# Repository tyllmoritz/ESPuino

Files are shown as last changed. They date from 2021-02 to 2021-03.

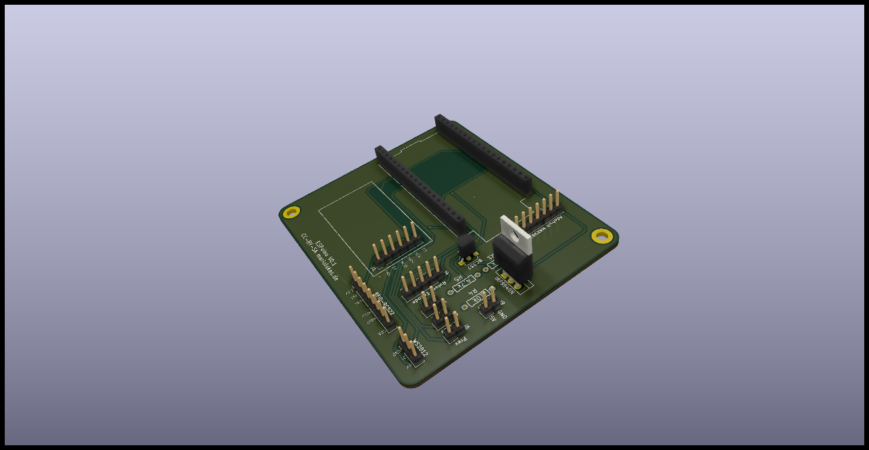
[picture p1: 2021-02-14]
PCBs/ESP32_Breakout_Carrier/Pictures/3d-model_without-ESP32.png

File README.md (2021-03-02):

# ESPuino - rfid-based musiccontroller based on ESP32 with I2S-DAC-support

## NEWS
* As the creator of TonUINO claims it's trademark right, my project has been renamed to ESPuino. I'm totally respecting this and have to admit that I've been not aware of that. However, I instantly renamed everything and hopefully I didn't forget any parts. Since my repository has moved, please make sure (at least if you're using git) to change the URL of your local repository. An explanation was kindly [written by user](https://github.com/biologist79/ESPuino/issues/81).
* Please note: inline with the renaming of the project, MQTT-topics were changed as well as they've been including the old name. Please make sure to change your local MQTT-configuration as well. Sorry to [those](https://github.com/biologist79/ESPuino/issues/83) that spent time on this to point out.
* EN: I've set up a primarily German-speaking community with much documentation. Also an international corner for non-German-speakers is available at https://forum.espuino.de. Github-Login can be used there but it's not necessary.
* DE: Ich habe ein primär deutschsprachiges Forum aufgesetzt, welches ich mit reichlich Doku versehen habe. Würde mich freuen, euch dort zu sehen: https://forum.espuino.de. Ihr könnt euch dort mit eurem Github-Login einloggen, jedoch auch "normal" anmelden. Dokumenation findet ihr insbesondere hier: https://forum.espuino.de/c/dokumentation/anleitungen/10
## Changelog
Moved to [another location](changelog.md) as it became to prominent here. Only last three events are kept:
* 25.02.2020: Added support for dynamic button-layout. Rotary-encoder is now optional and up to five buttons can be used.
* 25.02.2020: Actions can be freely assigned to buttons (multi-button(s), single-button(s) (short), single-button(s) (long))
* 25.02.2020: Added support for webcontrol: basic control (volume, play/pause, next, previous, first, last track) can now be controlled via webgui.
* 25.02.2020: Added support for .m4a and .wav-files.
* 26.02.2020: Shutdown via webgui is now available.
Thanks @QDaniel for the idea + basic implementation (first three features named above)!
## Known bugs
* Some webstreams don't run. Guess it's a combination of saturated connection-pool and lack of heap-memory. Works probably better if ESP32-WROVER (e.g. Lolin D32 pro) is used, as this chip has PSRAM. Advice: Don't enable modules (e.g. MQTT) if you don't need them as this could save memory (and trouble).
* English translation for webgui is currently pretty outdated. This will be fixed soon when i18n-support will be integrated.
## ESPuino - what's that?
The basic idea of ESPuino is to provide a way, to use the Arduino-platform for a music-control-concept that supports locally stored music-files without DRM-restrictions. This basically means that RFID-tags are used to direct a music-player. Even for kids this concept is simple: place an RFID-object (card, character) on top of a box and the music starts to play. Place another RFID-object on it and anything else is played. Simple as that.

The core of my implementation is based on the popular [ESP32 by Espressif](https://www.espressif.com/en/products/hardware/esp32/overview). Having WiFi-support out-of-the-box makes it possible to provide further features like an integrated FTP-server (to feed the player with music), smarthome-integration via MQTT, webradio and administration via webgui. However, my primary focus was to port the project to a modular base. Said this mp3-decoding is done in software with a dedicated uSD-card-slot and music-output is done via I2S-protocol. I did all my tests on [Adafruit's MAX98357A](https://learn.adafruit.com/adafruit-max98357-i2s-class-d-mono-amp/pinouts), [UDA1334](https://www.adafruit.com/product/3678) and [headphone-pcb](https://github.com/biologist79/ESPuino/tree/master/PCBs/Headphone%20with%20PCM5102a%20and%20TDA1308). Hopefully, not only in theory, other DACs that support I2S can be used as well.

## Hardware-setup
The heart of my project is an ESP32 on a [Wemos Lolin32 development-board](https://www.ebay.de/itm/4MB-Flash-WEMOS-Lolin32-V1-0-0-WIFI-Bluetooth-Card-Based-ESP-32-ESP-WROOM-32/162716855489). If ordered in China (Aliexpress, eBay e.g.) it's pretty cheap (around 4€) but even in Europe it's only around 8€. Make sure to install the drivers for the USB/Serial-chip (CP2102 e.g.). But probably it's better to use it's successor (which has battery-measurement already included): [Wemos Lolin D32](https://de.aliexpress.com/item/32808551116.html). Or, if you're planning to hear webstreams regularly, [Wemos Lolin D32 pro](https://de.aliexpress.com/item/32883116057.html) might be a good decision. It comes with uSD-slot onboard and because of its ESP32-WROVER-B has PSRAM included. PSRAM is used as webstream-cache and might be used more intensively in future.
* [MAX98357A (like Adafruit's)](https://de.aliexpress.com/item/32999952454.html)
* [uSD-card-reader; 3.3V only; supports SPI + SD-MMC](https://www.ebay.de/itm/Micro-SPI-Kartenleser-Card-Reader-2GB-SD-8GB-SDHC-Card-3-3V-ESP8266-Arduino-NEU/333796577968) or [cheaper](https://de.aliexpress.com/item/4000899753727.html)
* [RFID-reader RC-522](https://www.amazon.de/AZDelivery-Reader-Arduino-Raspberry-gratis/dp/B074S8MRQ7)
* [RFID-reader PN5180](https://de.aliexpress.com/item/4001278551831.html)
* [RFID-tags](https://www.amazon.de/AZDelivery-Keycard-56MHz-Schlüsselkarte-Karte/dp/B07TVJPTM7)
* [Neopixel-ring](https://de.aliexpress.com/item/32673883645.html)
* [Rotary Encoder](https://de.aliexpress.com/item/33041814942.html)
* [Buttons](https://de.aliexpress.com/item/32896285438.html)
* [Speaker](https://www.visaton.de/de/produkte/chassiszubehoer/breitband-systeme/fr-7-4-ohm)
* uSD-card: doesn't have to be a super-fast one; µC is limiting the throughput. Tested 32GB without any problems.
* uSD in SD-MMC (1 Bit) mode: Several devkits with onboard SD slot have support for this mode, e.g.: (https://de.aliexpress.com/item/4001229463219.html)
* optional replace the RFID-reader with a the better one: PN5180 comes with better RFID-range, less power-consumption and support for ISO-15693 / iCode SLIX2 tags (https://www.bing.com/shop?q=pn5180&FORM=SHOPTB)

## Getting Started
* Arduino-IDE can be used but you need to satisfy dependencies for all the libraries listed in `platformio.ini` manually.
* Instead I recommend to install Microsoft's [Visual Studio Code](https://code.visualstudio.com/). This is a popular and powerful IDE that gives you the ability to install tons of (well-supported) plugins.
* Install [Platformio Plugin](https://platformio.org/install/ide?install=vscode) into [Visual Studio Code](https://code.visualstudio.com/) and make sure to have a look at the [documentation](https://docs.platformio.org/en/latest/integration/ide/pioide.html). Step-by-step-manual is available [here](https://randomnerdtutorials.com/vs-code-platformio-ide-esp32-esp8266-arduino/.)
* Install [Git](https://git-scm.com/downloads) and make a copy ("clone") my repository to your local computer using `git clone https://github.com/biologist79/ESPuino.git`. Using git you can keep your local repository easily up to date without doing copy'n'paste. To keep it up to date run `git pull origin master`. Further infos [here}(https://stackoverflow.com/questions/1443210/updating-a-local-repository-with-changes-from-a-github-repository).
* (Optional) Install [Gitlens](https://marketplace.visualstudio.com/items?itemName=eamodio.gitlens) as plugin (to have advanced Git-support).
* Now, that the git-repository is saved locally, import this folder into Platformio as a project.
* There's a file called `platformio.ini`, that contains the configuration for different develboards (e.g. env:lolin32). Platformio supports hundrets of boards out of the box. So probably you need to change/extend that configuration. Guess Lolin32 is described in platformio.ini but you need Lolin D32, then lookup Platformio's [documentation](https://docs.platformio.org/en/latest/boards/espressif32/lolin_d32.html) to know what to change.
* `upload_port` and `monitor_port` should be autodetected (by the USB-ID of the serial-adapter). If this fails, please set these values depending on your operating system (Windows, Mac OS, Linux).
* Edit `src/settings.h` according your needs. Especially don't forget to set `HAL` depending on your develboard.
* Edit board-specific (`HAL`) config-file (e.g. `settings-lolin32.h` for Lolin32 or `settings-lolin_d32.h` for Lolin D32). If you're running a board that is not listed there: start with `settings-custom.h` and change it according your needs.
* Connect your develboard via USB, click the alien-head to the left and run `Upload and Monitor`. All libraries necessary should be fetched in background now followed by code-compilation. After that, your ESP32 is flashed with the firmware. Depending on your develboard it might me necessary to push a button in order to allow ESP32 to enter flashmode (not necessary für Lolin32, D32 und D32 pro).
* Now have a look at the serial-output at the bottom of Visual Studio Code's windows. At the first run there might appear a few error-messages (related to missing entries in NVS). Don't worry, this is just normal. However, make sure SD is running as this is mandatory!
* If everything ran fine, at the first run, ESPuino should open an access-point with the name "ESPuino". Join this WiFi with your computer (or mobile) and enter `192.168.4.1` to your webbrowser. Enter WiFi-credentials and the hostname. After saving the configuraton, restart ESPuino. Hint: I tried to connect this access-point via Android mobile. Basically that's no problem, but as my mobile detected there'd be no internet-connection, it keept LTE-connection open and prevented me from connecting to `192.168.4.1`. So if in doubts use a computer.
* After reboot ESPuino tries to join your WiFi (with the credentials previously entered). If that was successful, an IP is shown in the serial-console of Visual Studio Code. You can call ESPuino's GUI using a webbrowser via this IP; make sure to allow Javascript. If mDNS-feature is active in `src/settings.h`, you can use the hostname configured extended by .local instead the IP. So if you configured `espuino` as hostname, you can use `espuino.local` for webgui and FTP.
* Via FTP you can upload data (but don't expect it to be super fast). It's round about 185 kb/s if SD is in SPI-mode and 310 kB/s if SD is in MMC-mode.
* FTP needs to be activated after boot! Don't forget to assign action `ENABLE_FTP_SERVER` in `settings.h` to be able to activate it. Neopixel flashes green (1x) if enabling was successful. It'll be disabled automatically after next reboot. Means: you have to enable it every time you need it (if reboot was in between). Sounds annoying and maybe it is, but's running this way in order to have more heap-memory available (for webstream) if FTP isn't running.
* Via webbrowser you can configure various settings and pair RFID-tags with actions. If MQTT/FTP-support was not compiled, their config-tabs won't appear.

## Prerequisites / tipps
* Open settings.h
* choose if optional modules (e.g. MQTT, FTP, Neopixel) should be compiled/enabled
* Make sure to edit/review button-layout. Default-design is three buttons and a rotary-encoder. All actions available are listed in `values.h` (values >= 100).
* For debugging-purposes serialDebug can be set to ERROR, NOTICE, INFO or DEBUG.
* If MQTT=yes, set the IP or hostname of the MQTT-server accordingly and check the MQTT-topics (states and commands)
* Advice: don't enable MQTT if there's no broker around because network-timeouts can really be a PITA.
* If Neopixel enabled: set NUM_LEDS to the LED-number of your Neopixel-ring and define the Neopixel-type using `#define CHIPSET`
* If you're using Arduino-IDE please make sure to change ESP32's partition-layout to `No OTA (2MB APP/2MB Spiffs)` as otherwise the sketch won't fit into the flash-memory.
* Open board-specific config-file and edit according your needs.
* If you want to monitor battery's voltage, make sure to enable `MEASURE_BATTERY_VOLTAGE`. Use a voltage-divider as voltage of a LiPo is way too high for ESP32 (only 3.3V supported!). For my tests I connected VBat with a serial connection of 130k + 130k resistors (VBat(+)--130k--X--130k--VBat(-)). X is the measure-point where to connect the GPIO to. If using Lolin D32 or Lolin D32 pro, make sure to leave both resistor-values unchanged at 100k. Same for GPIO: unchanged at 35.
Please note: via GUI upper and lower voltage cut-offs for visualisation of battery-voltage (Neopixel) is available. Additional GUI-configurable values are interval (in minutes) for checking battery voltage and the cut off-voltage below whose a warning is shown via Neopixel.
* If you're using a headphone-pcb with a [headphone jack](https://www.conrad.de/de/p/cliff-fcr1295-klinken-steckverbinder-3-5-mm-buchse-einbau-horizontal-polzahl-3-stereo-schwarz-1-st-705830.html) that has a pin to indicate if there's a plug, you can use this signal along with the feature `HEADPHONE_ADJUST_ENABLE` to limit the maximum headphone-voltage automatically. As per default you have to invert this signal (with a P-channel MOSFET) and connect it to GPIO22.
* Enabling `SHUTDOWN_IF_SD_BOOT_FAILS` is really recommended if you run your ESPuino in battery-mode without having a restart-button exposed to the outside of ESPuino's enclosure. Because otherwise there's no way to restart your ESPuino and the error-state will remain until battery is empty (or you open the enclosure, hehe).
* Enabling `PLAY_LAST_RFID_AFTER_REBOOT` will tell ESPuino to remember the last RFID-tag played after next reboot. So rebooting ESPuino will end up in autoplay. I don't really recommend this feature because if you use it along with a webstream, in case of streaming-issues this might end up in an infinite loop.

## SD-card: SPI or SD-MMC (1 bit)-mode?
Having SD working is mandatory. However, there are two modes available to access SD-cards: SPI and SD-MMC (1 bit).<br />
Advantages SD-MMC (1 bit) over SPI:
* Needs only three GPIOs (instead of four)
* It's faster. FTP-upload: 298 kiB vs 178 kiB. HTTP-upload: 372 kiB vs 184 kiB. (tested with filesize of 70.7 MiB.<br />
So why using SPI if SD-MMC seems to be better? The primary problem of SD-MMC is: you cannot choose different GPIOs. That doesn't sound bad but this can (depending on the uSD-card-reader-module) be a problem because maybe GPIO2 is pulled HIGH to 3.3V by a 10k-resistor. For example this is the case when using the reader-module named above in hardware-setup. It's a problem because if GPIO2 is pulled high at boot, ESP32 doesn't enter flash-mode. As soon as flash-mode is entered, it's no longer a problem. However, this behaviour can be an issue if ESP32 is deeply "burried" in ESPuino's enclosure and you want to update its firmware. But fortunately there's a way to bypass this problem: remove the [pullup-resistor shown in the picture](https://raw.githubusercontent.com/biologist79/ESPuino/master/pictures/Pullup-removal.jpg). It can be removed safely because if MMC-mode is set, pullup is done in software using `pinMode(2, INPUT_PULLUP);`. So it's not really a problem but you have to take note of that!

## RFID: RC522 or PN5180?
RC522 is so to say the Tonuino-standard. It's cheap and works, but RFID-tag has to be placed near the reader. PN5180 instead has better RFID range/sensitivity and can read ISO-15693 / iCode SLIX2-tags aka 'Tonies' (you need a password to read Tonies). You can also wake-up the board with the card. Disadvantages: is a bit more expensive and needs more GPIOs (6/7 instead of 4). Refer PN5180's wire-section below for further informations. Hint: if using 3.3V make sure to connect PN5180 to +5V AND 3.3V. Sounds weird but it's necessary.

## 3.3 or 5V?
* Why 3.3V? Because: if you plan to use battery-mode with a LiPo, there's no 5 V available (unless USB is connected).
That's why my design's focus is 3.3 V. If you want to use 5 V - do so, but be advised it's not compatible with LiPo-battery-mode. The Mosfet-circuit for saving power in deepsleep (see [Lolin32-schematics](https://github.com/biologist79/ESPuino/blob/master/PCBs/Wemos%20Lolin32/Pictures/Tonuino%20V2-Schematics.pdf) as reference) works as well for 5 V.
* MAX98357a: provides more power at 5 V but also runs at 3.3 V. Anyway: it's still loud enough (in my opinion).
* Neopixel: specification says it needs 5 V but also runs at 3.3 V.
* RC522: needs 3.3 V (don't power with 5 V!)
* PN5180: at 3.3 V make sure to connect both 5 V and 3.3 V-pins to 3.3 V.
* SD: needs 3.3 V but if voltage-regulator is onboard, it can be connected to 5 V as well
* Rotary encoder: 3.3 V (don't power with 5 V! Encoder doens't care if connected to 3.3 or 5 V, but GPIOs of ESP32 do!)

## Wiring (general)
Depending on the develboard you're using and the needs you have, there are different options available.
A lot of wiring is necessary to get ESPuino working. After my first experiments on a breadboard I soldered all the stuff onto a PCB in order to avoid wild-west-cabling. Especially for the interconnect between µC and uSD-card-reader make sure to use short wires (like 10cm or so)! As of my experience with a breadbord, male/male-connectors are better than female/female-connectors. Important: you can easily connect another I2S-DACs by just connecting them in parallel to the I2S-pins (DIN, BCLK, LRC). This is true for example if you plan to integrate a [line/headphone-pcb](https://www.adafruit.com/product/3678). In general, this runs fine. But unfortunately especially this board lacks of a headphone jack, that takes note if a plug is inserted or not. Best way is to use a [headphone jack](https://www.conrad.de/de/p/cliff-fcr1295-klinken-steckverbinder-3-5-mm-buchse-einbau-horizontal-polzahl-3-stereo-schwarz-1-st-705830.html) that has a pin that is pulled to GND, if there's no plug and vice versa. Using for example a MOSFET-circuit, this GND-signal can be inverted in a way, that MAX98357.SD is pulled down to GND if there's a plug. Doing that will mute MAX98537a and so turn off the speaker immediately if there's a plug and vice versa. Have a look at the PCB-folder in order to view the detailed solution. Here's an example for such a [headphone-pcb](https://github.com/biologist79/ESPuino/tree/master/PCBs/Headphone%20with%20PCM5102a%20and%20TDA1308) that makes use of GND.<br />
Have a look at the PCB-folder. I provided PCBs for a number of develboards. Probably this makes things easier for you.

## Wiring (2 SPI-instances: RC522 + SD + 3 buttons + rotary-encoder)
Uses two SPI-instances. The first one for the RFID-reader and the second for SD-card-reader. This is also the [setup, I personally use](https://github.com/biologist79/ESPuino/tree/master/PCBs/Wemos%20Lolin32).<br />
| ESP32 (GPIO)  | Hardware | Pin | Comment |
| --- | --- | --- | --- |
| 3.3 (5) V | SD-reader | VCC | Connect to p-channel MOSFET for power-saving when µC is off  |
| GND | SD-reader | GND | |
| 15 | SD-reader | CS | |
| 13 | SD-reader | MOSI | |
| 16 | SD-reader | MISO | |
| 14 | SD-reader | SCK | |
| 3.3 V | RFID-reader | 3.3V | (Connect directly to GPIO 17 for power-saving when µC is off)  |
| GND | RFID-reader | GND | |
| 21 | RFID-reader | CS/SDA | |
| 23 | RFID-reader | MOSI | |
| 19 | RFID-reader | MISO | |
| 18 | RFID-reader | SCK | |
| 5 / 3.3 V | MAX98357 | VIN | Connect to p-channel MOSFET for power-saving when µC is off  |
| GND | MAX98357 | GND | |
| 25 | MAX98357 | DIN | |
| 27 | MAX98357 | BCLK | |
| 26 | MAX98357 | LRC | |
| --- | MAX98357 | SD | Info: if pulled down to GND amp will turn off |
| 34 | Rotary encoder | CLK | Change CLK with DT if you want to change the direction of RE |
| 35 | Rotary encoder | DT | Change CLK with DT if you want to change the direction of RE |
| 32 | Rotary encoder | BUTTON | |
| 3.3 V | Rotary encoder | + | |
| GND | Rotary encoder | GND | |
| 4 | Button (next) | | |
| GND | Button (next) | | |
| 2 | Button (previous) | | |
| GND | Button (previous) | | |
| 5 | Button (pause/play) | | |
| GND | Button (pause/play) | | |
| 3.3 V | Neopixel | V | Connect to p-channel MOSFET for power-saving when µC is off  |
| GND | Neopixel | G | |
| 12 | Neopixel | DI | |
| 17 | N-channel Mosfet | Gate | |
| 33 | Voltage-divider / BAT | | Optional: voltage-divider to monitor battery-voltage |
| 22 | Headphone jack | | Optional: if pulled to ground, headphone-volume is set |

Optionally, GPIO 17 can be used to drive a Mosfet-circuit in order to switch off peripherals (SD, Neopixel, RFID and MAX98357a) if ESP32 is in deepsleep. Please refer the schematics for my [Lolin32-PCB](https://github.com/biologist79/ESPuino/blob/master/PCBs/Wemos%20Lolin32/Pictures/Tonuino-Lolin32-Schematics.pdf) for further informations. If you need further informations on transistor-circuits visit this [website](https://dl6gl.de/schalten-mit-transistoren.html). <br />
In general I recommend using a [uSD-card-reader](https://www.ebay.de/itm/Micro-SPI-Kartenleser-Card-Reader-2GB-SD-8GB-SDHC-Card-3-3V-ESP8266-Arduino-NEU/333796577968) that can be run solely with 3.3V (doesn't have a voltage-regulator). This is because if 3.3V go through the voltage regulator a small voltage-drop will be introduced, which may lead to SD-malfunction as the resulting voltage is a bit too low. Vice versa if you want to connect your reader solely to 5V, make sure to have one WITH a voltage regulator :-). And by the way: when LiPo-battery is connected, there's no 5V. That's why I designed my [Lolin-PCBs](https://github.com/biologist79/ESPuino/tree/master/PCBs/Wemos%20Lolin32) with 3.3V only.

## Wiring (SD-card in 1 Bit SD-MMC mode) different to above
| ESP32 (GPIO)  | Hardware | Pin | Comment |
| --- | --- | --- | --- |
| -- | SD-reader | CS | no CS required |
| 15 | SD-reader | MOSI | |
| 2 | SD-reader | MISO | make sure there's no [hardware-pullup](https://raw.githubusercontent.com/biologist79/ESPuino/master/pictures/Pullup-removal.jpg) for MISO |
| 14 | SD-reader | SCK | |

Make sure to enable `SD_MMC_1BIT_MODE` if you want to use this feature. Don't(!) enable `SINGLE_SPI_ENABLE`. SD-MMC-mode requires these fixed PINs listed above. You can find a good comparison of different SD-card-modes here: (https://www.instructables.com/Select-SD-Interface-for-ESP32/).
Advice: Double check that above PINs are not used elsewhere (e.g. GPIO2 is used as PREVIOUS_BUTTON as per default in settings.h).

## Wiring (1 SPI-instance: RC522 + SD + 3 buttons + rotary-encoder) [EXPERIMENTAL, maybe not working!]
Basically the same as using 2 SPI-instances but...
In this case RFID-reader + SD-reader share SPI's SCK, MISO and MOSI. But make sure to use different CS-pins. Have to admit I had some problems to get this running. Seems to be connected properly, but nothing happens when an RFID-tag is applied. Maybe anybody else wants to point out :-)

| ESP32 (GPIO)  | Hardware | Pin | Comment |
| --- | --- | --- | --- |
| 3.3 (5) V | SD-reader | VCC | Connect to p-channel MOSFET for power-saving when µC is off  |
| GND | SD-reader | GND | |
| 15 | SD-reader | CS | Don't share with RFID! |
| 3.3 V | RFID-reader | 3.3V | Connect directly to GPIO 17 for power-saving when µC is off  |
| GND | RFID-reader | GND | |
| 21 | RFID-reader | CS/SDA | Don't share with SD! |
| 23 | RFID+SD-reader | MOSI | |
| 19 | RFID+SD-reader | MISO | |
| 18 | RFID+SD-reader | SCK | |
| 5 / 3.3 V | MAX98357 | VIN | Connect to p-channel MOSFET for power-saving when µC is off  |
| GND | MAX98357 | GND | |
| 25 | MAX98357 | DIN | |
| 27 | MAX98357 | BCLK | |
| 26 | MAX98357 | LRC | |
| --- | MAX98357 | SD | Info: if pulled down to GND amp will turn off |
| 34 | Rotary encoder | CLK | Change CLK with DT if you want to change the direction of RE |
| 35 | Rotary encoder | DT | Change CLK with DT if you want to change the direction of RE |
| 32 | Rotary encoder | BUTTON | |
| 3.3 V | Rotary encoder | + | |
| GND | Rotary encoder | GND | |
| 4 | Button (next) | | |
| GND | Button (next) | | |
| 2 | Button (previous) | | |
| GND | Button (previous) | | |
| 5 | Button (pause/play) | | |
| GND | Button (pause/play) | | |
| 5 / 3.3 V | Neopixel | V | Connect to p-channel MOSFET for power-saving when µC is off  |
| GND | Neopixel | G | |
| 12 | Neopixel | DI | |
| 17 | N-channel Mosfet | Gate | |
| 33 | Voltage-divider / BAT | | Optional: voltage-divider to monitor battery-voltage |
| 22 | Headphone jack | | Optional: if pulled to ground, headphone-volume is set |

## Wiring (PN5180 instead of MFRC522) different to above
PN5180-reader needs at least two more GPIOs: RESET and BUSY. Double check pin-conflicts! `RFID_READER_TYPE_PN5180` needs to be enabled to use this feature. Make sure to disable `RFID_READER_TYPE_MFRC522` if doing so!
You can enable low power card-detection with `PN5180_ENABLE_LPCD`, but this needs another GPIO for IRQ. With low power card detection (LPCD) you can wake-up the ESP32 from deep-sleep just by applying a card to the reader. You need a PN5180-firmware >= 4.0. Most china-boards comes with older firmware. The latest firmware can be flashed with this [project](https://github.com/abidxraihan/PN5180_Updater_ESP32).

| ESP32 (GPIO)  | Hardware | Pin | Comment |
| --- | --- | --- | --- |
| 3.3 V | PN5180 RFID-reader | 3.3V | Connect directly to GPIO 17 for power-saving when µC is off |
| 3.3 V | | 3.3V | For low power card detection mode (LPCD) connect directly to 3.3V |
| 5 / 3.3 V | PN5180 RFID-reader | 5V | Don't forget to connect this pin the same way as 3.3V |
| GND | PN5180 RFID-reader | GND | |
| 21 | PN5180 RFID-reader | CS/SDA | Same as MFRC522. Don't share with SD! |
| 23 | PN5180 RFID-reader | MOSI | Same as MFRC522 |
| 19 | PN5180 RFID-reader | MISO | Same as MFRC522 |
| 18 | PN5180 RFID-reader | SCK | Same as MFRC522 |
| 16 | PN5180 RFID-reader | BUSY | be aware of SD MISO if running in SPI mode |
| 22 | PN5180 RFID-reader | RST | be aware of Headphone jack PIN |
| 39 | PN5180 RFID-reader | IRQ | optional, used for low power card detection (LPCD) |

## Wiring (custom) / different pinout
When using a develboard with SD-card-reader already integrated (Lolin D32 Pro, several TTGO-boards), the pinouts described above my not fit. Feel free to change them according your needs. Additionaly some boards may use one or some of the GPIOs I used for their internal purposes and that reason for are maybe not exposed via pin-headers. However, having them exposed doesn't mean they can be used without limits. This is because some GPIOs have to be logical LOW or HIGH at start/boot for example and this is probably not the case when connecting stuff to it. Feel free to adjust the GPIOs proposed by me (but be adviced it could take a while to get it running). If you encounter problems please refer the board's manual first. <br />
[Here](https://github.com/biologist79/ESPuino/tree/master/Hardware-Plaforms/ESP32-A1S-Audiokit) I described a solution for a board with many GPIOs used internally and a very limited number of GPIOs exposed. That's why I had to use different SPI-GPIOs for RFID as well. Please note I used a slightly modified [RFID-lib](https://github.com/biologist79/ESPuino/tree/master/Hardware-Plaforms/ESP32-A1S-Audiokit/lib/MFRC522) there. Please note: the code-basis is outdated. Will need to re-integrate it into my master-branch...

## WiFi
WiFi is mandatory for webgui, FTP and MQTT. However, WiFi can be temporarily or permanently disabled. There are two ways to do that:
* Use a special modification-card that can be configured via webgui
* Press previous-key (and keep it pressed) + press next-button in parallel shortly. Now release both.
This toggles the current WiFi-status: if it's currently enabled, it will be disabled instantly and vice versa. Please note: this WiFi-status will remain until you change it again, which means, that ESPuino will remember this state after the next reboot. Having Wifi enabled is indicated in idle-mode (no playlist active) with four *white* slow rotating LEDs whereas disabled WiFi is represented by those ones coloured *green*. Bluetooth-mode is indicated by *blue* LEDs.

## Bluetooth
ESPuino can be used as bluetooth-sink (a2dp). This mode can be enabled/disabled via a RFID-modification-card. Applying one will restart ESPuino immediately. Two modes are available which are toggled in between: "normal" and "bluetooth". Normal means: SD + WiFi are available whereas in mode "bluetooth" only bluetooth-support can be provided. If bluetooth is active, this is indicated by four slow rotating *blue* LEDs. Now you can stream to your ESPuino e.g. with your mobile device. Tested this with Android 8 and worked 100% flawless.
## After ESPuino is connected to your WiFi
After bringing ESPuino part of your LAN/WiFi, the 'regular' webgui is available at the IP assigned by your router (or the configured hostname). Using this GUI, you can configure:
* WiFi
* Binding between RFID-tag, file/directory/URL and playMode
* Binding between RFID-tag and a modification-type
* MQTT
* FTP
* Initial volume, maximum volume (speaker / headphone), brightness of Neopixel (nightmode / default) and inactivity-time

Webgui #1:


Webgui #2:


Webgui #3:


Webgui #4:


Webgui #5:


Webgui #6:


Webgui #7:


Webgui: websocket broken:


Webgui: action ok:


Please note: as you apply a RFID-tag to the RFID-reader, the corresponding ID is pushed to the GUI. So there's no need to enter such IDs manually (unless you want to). Filepath can be filled out by selecting a file/directory in the tree.
IMPORTANT: Every time you add, delete or rename stuff on the SD-card, it's necessary to rebuild the json-indexfile. Simply click on the refresh-button below the filetree and wait until it's done. This is because all operations of the filebrowser rely on this file in order to provide a fast way to access all the files and directories.

## Interacting with ESPuino
### Playmodes
It's not just simply playing music; different playmodes are supported:
* `single track` => plays one track one time
* `single track (loop)` => plays one track forever
* `audiobook `=> single file or playlist/folder; last play-position (file and playlist) is saved (when pushing pause or moving to another track) and re-used next time
* `audiobook` (loop) => same as audiobook but loops forever
* `folder/playlist (alph. sorted)` => plays all tracks in alph. order from a folder one time
* `folder/playlist (random order)` => plays all tracks in random order from a folder one time
* `folder/playlist (alph. sorted)` => plays all tracks in alph. order from a folder forever
* `folder/playlist (random order)` => plays all tracks in random order from a folder forever
* `webradio` => always only one "track": plays a webstream

### Modification RFID-tags
There are special RFID-tags, that don't start music by themself but can modify things. If applied a second time, it's previous action/modification will be reversed. Please note: all sleep-modes do dimming (Neopixel) automatically because it's supposed to be used in the evening when going to bed. Well, at least that's my children's indication :-) So first make sure to start the music then use a modification-card in order to apply your desired modification:
* lock/unlock all buttons
* sleep after 5/30/60/120 minutes
* sleep after end of current track
* sleep after end of playlist
* sleep after five tracks
* dimm neopixel
* current track in loop-mode (is "stronger" than playlist-loop but doesn't overwrite it!)
* playlist in loop-mode
* track und playlist loop-mode can both be activated at the same time, but unless track-loop isn't deactivated, playlist-loop won't be effective
* Toggle WiFi (enable/disable) => disabling WiFi while webstream is active will stop the webstream instantly!
* Toggle Bluetooth (enable/disable) => restarts ESPuino immediately

### Neopixel-ring (optional)
Indicates different things. Don't forget configuration of number of LEDs via #define NUM_LEDS
* While booting: every second LED (rotating orange)
* Unable to mount SD: LEDs flashing red (will remain forever unless SD-card is available or `SHUTDOWN_IF_SD_BOOT_FAILS` is active)
* IDLE: four LEDs slow rotating (white if WiFi enabled; green if WiFi disabled)
* BLUETOOTH: four LEDs slow rotating coloured blue
* ERROR: all LEDs flashing red (1x) if an action was not accepted
* OK: all LEDs flashing green (1x) if an action was accepted
* BUSY: violet; four fast rotating LEDs when generating a playlist. Duration depends on the number of files in your playlist.
* track-progress: rainbow; number of LEDs relative to play-progress
* playlist-progress: blue; appears only shortly in playlist-mode with the beginning every new track; number of LEDs relative to progress
* webstream: two slow rotating LEDs that change their colours rainbow-wise as the stream proceeds
* volume: green => red-gradient; number of LEDs relative from current to max volume
* switching off: red-circle that grows until long-press-time is reached
* buttons locked: track-progress-LEDs coloured red
* paused: track-progress-LEDs coloured orange
* rewind: if single-track-loop is activated a LED-rewind is performed when restarting the given track
* (Optional) Undervoltage: flashes three times red if battery-voltage is too low. This voltage-level can be configured via GUI.
* (Optional) Short press of rotary encoder's button provides battery-voltage visualisation via Neopixel. Upper und lower voltage cut-offs can be adjusted via GUI. So for example if lower voltage is set to 3.2 V and upper voltage to 4.2 V, 50% of the LEDs indicate a voltage of 3.7 V.

Please note: some Neopixels use a reversed addressing which leads to the 'problem', that all effects are shown
counter clockwise. If you want to change that behaviour, just enable `NEOPIXEL_REVERSE_ROTATION`.

### Buttons
Important: this section describes my default-design: 3 buttons + rotary-encoder. Feel free to change button-number and button-actions according your needs in `settings.h` and your develboard-specific config-file (e.g. `settings-lolin32.h`). At maximum you can activate five buttons + rotary-encoder.
Minimum duration for long press in ms is defined by `intervalToLongPress`.
* previous (short): previous track / beginning of the first track if pressed while first track is playing
* previous (long): first track of playlist
* next (short): next track of playlist
* next (long): last track of playlist
* pause/play (short/long): pause/play
* rotary encoder (turning): vol +/-
* rotary encoder (button long): switch off (only when on)
* rotary encoder (button short): switch on (when switched off)
* rotary encoder (button short): show battery-voltage via Neopixel (when switched on and `MEASURE_BATTERY_VOLTAGE` is active)
* previous (long; keep pressed) + next (short) + release (both): toggle WiFi enabled/disabled

### Music-play
* Music starts to play right after a valid RFID-tag was applied
* If `PLAY_LAST_RFID_AFTER_REBOOT` is active, ESPuino will remember the last RFID applied => music-autoplay (if in doubts don't use this feature).
* If a folder should be played that contains many mp3s, the playlist generation can take a few seconds. Please note that a file's name including path cannot exceed 255 characters.
* While playlist is generated Neopixel indicates BUSY-mode.
* After last track was played, Neopixel indicates IDLE-mode.
* In audiobook-mode, last play-position is remembered (position in actual file and number of track, respectively) when a new track begins of if pause-button was hit.
* In webstream-mode the stream will instantly stop if WiFi-status is toggled to disabled. ESPuino will return to idle-mode and wait for new RFID-tag.

### Audiobook-mode
This mode is different from the other ones because the last playposition is saved. Playposition is saved when...
* next track starts.
* first/previous/last track requested by button.
* pause was pressed.
* playlist is over (playposition is set back to the first track and file-position 0).
* Please note: last playposition is not saved when applying a new RFID-tag. This is intended because otherwise you woldn't have a possibility to not save it.

### Webinterface-configuration
After having ESPuino running on your ESP32 in your local WiFi, the webinterface-configuration is accessable. Using this GUI you can configure:
* Wifi-configuration (Wifi-SSID, Wifi-password, ESPuino's name (for nameserver))
* Link between RFID-tag and corresponding action
* (optional) MQTT-configuration (broker's IP)
* (optional) FTP-configuration (username and password)
* General-configuration (volume (speaker + headphone), neopixel-brightness (night-mode + initial), sleep after inactivity)
* Basic music-control: first, last, previous, next-track; volume +/-; play/pause

### FTP (optional)
* FTP needs to be activated after boot! Don't forget to assign action `ENABLE_FTP_SERVER` in `settings.h` to be able to activate it! Neopixel flashes green (1x) if enabling was successful. It'll be disabled automatically after next reboot. Means: you have to enable it every time you need it (if reboot was in between). Sounds annoying and maybe it is, but's running this way in order to have more heap-memory available (for webstream) if FTP isn't running.
* In order to avoid exposing uSD-card or disassembling ESPuino all the time for adding new music, it's possible to transfer music to the uSD-card using FTP.
* Default-user and password are set to `esp32` / `esp32` but can be changed later via GUI.
* Make sure to set the max. number of parallel connections to ONE in your FTP-client and the charset to CP437. CP437 is important if you want to use german umlauts (öäüß).
* Secured FTP is not available. So make sure to disable SSL/TLS.
* Software: my recommendation is [Filezilla](https://filezilla-project.org/) as it's free and available for multiple platforms.
* Don't expect a super fast data-transfer; it's around 185 kB/s (SPI-mode) and 310 kB/s (MMC-mode).
* Please note: if music is played in parallel, this rate decrases dramatically! So better stop playback when doing a FTP-transfer.

### Energy saving
As already described in the modify-section, there are different sleepmodes available. Additionaly µC will be put into deepsleep after 10 minutes of inactivity (configurable my maxInactivityTime) unless ESPuino doesn't play music, has a FTP-client connected and any input via buttons. Every button-interaction resets the counter.

### MQTT (optional)
Everything that can be controlled via RFID-tags and buttons, can also be controlled via MQTT (excepting toggling WiFi-status as this doesn't make sense). All manual interactions (buttons, RFID-tags) are also sent to MQTT in parallel, so everything is always in-sync (unless Wifi/MQTT-connection is broken). In my home-setup I'm using [openHAB](https://www.openhab.org/) to "encapsulate" MQTT into a nice GUI, that's accessible via APP + web. I [described](https://github.com/biologist79/ESPuino/tree/master/openHAB) a sample-config for openHAB2. However, meanwhile openHAb3 is available and all the stuff described can also be configured via GUI. Be advised that openHAB is pretty complex and you have to spend some time to get familiar with it.

### Supported file/stream-types
Please refer [ESP32-audioI2S](https://github.com/schreibfaul1/ESP32-audioI2S), as this is the library I used for music-decoding. Make sure to update especially this library regularly as it's development is still in progress.

### Backups
As all assignments between RFID-IDs and actions (playmode, file to play...) is saved in ESP's NVS, the problem is that it's all gone when the ESP is broken. So that's where a backup comes into play. So every time you change or add a new assignment between a RFID-tag and an action via GUI, a backup-file is saved on the uSD-card. The file's name can be changed via `backupFile`. So better don't delete it! Using the webgui you can use the upload-form to import such a file. To be honest: Sometimes I had some issues with Firefox doing this whereas Safari turned out to do it right. Don't know why :-(.

## Smarthome (optional)
As already described, MQTT is supported. In order to use it it's necessary to run a MQTT-broker; [Mosquitto](https://mosquitto.org/) for instance. After connecting to it, ESPuino subscribes to all command-topics. State-topics are used to push states to the broker in order to inform others if anything changed (change of volume, new playlist, new track... name it). Others, like openHAB, subscribe to state-topics end send commands via command-topics. So it's not just limited to openHAB. It's just necessary to use a platform, that supports MQTT. For further informations (and pictures) refer the [subfolder](https://github.com/biologist79/ESPuino/tree/master/openHAB).

## MQTT-topics and their ranges
Feel free to use your own smarthome-environments (instead of openHAB). The MQTT-topics available are described as follows. Please note: if you want to send a command to ESPuino, you have to use a cmnd-topic whereas ESPuino pushes its states back via state-topics. So guess you want to change the volume to 8 you have to send this number via topic-variable `topicLoudnessCmnd`. Immediately after doing to, ESPuino sends a conformation of this command using `topicLoudnessState`. To get hands on MQTT I recommend this [one](https://www.hivemq.com/mqtt-essentials/) as introducton (covers more than you need for ESPuino).

| topic-variable | range | meaning |
| --- | --- | --- |
| topicSleepCmnd | 0 or OFF | Power off ESPuino immediately |
| topicSleepState | ON or OFF | Sends ESPuino's current/last state |
| topicRfidCmnd | 12 digits | Set number of RFID-tag which 'emulates' an RFID-tag (e.g. `123789456089`) |
| topicRfidState | 12 digits | ID of current RFID-tag (if not a modification-card) |
| topicTrackState | String | Sends current track number, total number of tracks and full path of curren track. E.g. "(2/10) /mp3/kinderlieder/Ri ra rutsch.mp3" |
| topicTrackControlCmnd | 1 -> 7 | `1`=stop; `2`=unused!; `3`=play/pause; `4`=next; `5`=prev; `6`=first; `7`=last |
| topicLoudnessCmnd | 0 -> 21 | Set loudness (depends on minVolume / maxVolume) |
| topicLoudnessState | 0 -> 21 | Sends loudness (depends on minVolume / maxVolume |
| topicSleepTimerCmnd | EOP | Power off after end to playlist |
| | EOT | Power off after end of track |
| | EO5T | Power off after end of five tracks |
| | 1 -> 2^32 | Duration in minutes to power off |
| | 0 | Deactivate timer (if active) |
| topicSleepTimerState | various | Sends active timer (`EOP`, `EOT`, `EO5T`, `0`, ...) |
| topicState | Online, Offline | `Online` when powering on, `Offline` when powering off |
| topicCurrentIPv4IP | IPv4-string | Sends ESPuino's IP-address (e.g. `192.168.2.78`) |
| topicLockControlsCmnd | ON, OFF | Set if controls (buttons, rotary encoder) should be locked |
| topicLockControlsState  | ON, OFF | Sends if controls (buttons, rotary encoder) are locked |
| topicPlaymodeState | 0 - 10 | Sends current playmode (single track, audiobook...; see playmodes) |
| topicRepeatModeCmnd | 0 - 3 | Set repeat-mode: `0`=no; `1`=track; `2`=playlist; `3`=both |
| topicRepeatModeState | 0 - 3 | Sends repeat-mode |
| topicLedBrightnessCmnd  | 0 - 255 | Set brightness of Neopixel |
| topicLedBrightnessState | 0 - 255 | Sends brightness of Neopixel |
| topicBatteryVoltage | float | Voltage (e.g. 3.81) |

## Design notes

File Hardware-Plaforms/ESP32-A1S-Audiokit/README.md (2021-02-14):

# ESPuino based on ESP32-A1S Audio-Development-Kit

AI-Tinker released (almost two years ago or so) a development-board that contains an ESP32-A1S, which means a DAC is already included upfront. It's sorta ready to use but in the end, to make it compatible with ESPuino, there's some work waiting.

## Things to know
* As there's a lack of GPIOs, it's necessary to share a single SPI-instance by SD and RFID.
* As per default, [RFID-Lib](https://github.com/miguelbalboa/rfid/) doesn't support to run on non-default-SPI-GPIOs. So that's why I used a [modified one](https://github.com/madias123/STM32duino-RFID-Mp3-Player/tree/master/3d%20party%20libraries%20(modified)/MFRC522).
* The board provides 6 keys but due to lack of free GPIOs, we need them for other purposes. Additionaly the problem is, that all keys are equipped with capacitors (maybe to debounce) which makes it hard to use those GPIOs for other purposes. That's why I unsoldered R66, 67, 68, 69, 70 (all 0 Ohms) to free these GPIOs from the capacitors.
* Please note: key1 still works but if you additionaly want to use keys2-6, you can use GPIO36 along with analogRead() by using voltage-dividers. But first one has to calculate + solder resistor-pairs 56/61, 57/62, 58/63, 59/64 to 'build' those voltage-dividers. Without doing that online Key1 is usable as it doesn't need resistors. However, didn't solder/test dividers so far.
* When switching over to use analogRead() one has to modify buttonHandler() in my code.
* Additionaly I unsoldered resistor R14 in order to deactivate LED D4 (probably not necessary)

## GPIOS
Please note: You need to unsolder R66, 67, 68, 69, 70 first to use the board that way!

| GPIO | Usage | Pin | Comment |
| --- | ---| --- | --- |
| 0 | internal (I2S) | MCLK | |
| 2 | SD (int.) + RFID | SPI.MISO | Solder wire to SD.7 for RFID |
| 4 | Rot. Encoder | BUTTON | Solder wire to SD.8 |
| 5 | Rot. Encoder | CLK | Via 14-pin-header |
| 12 | RFID | SPI.CS | Via JT_MTDI |
| 13 | internal (SD) | SPI.CS | CS for SD |
| 14 | SD (int.) + RFID | SPI.SCK | Via JT_MTMS |
| 15 | SD (int.) + RFID | SPI.MOSI | Via JT_MTDO |
| 18 | Rot. Encoder | DT | Via 14-pin-header |
| 19 | Power | | For switch on/off external hardware via MOSFET (optional) |
| 21 | internal (amp) | | To switch on/off amp |
| 22 | unused? | | Via 14-pin-header |
| 23 | Neopixel | DI | Via 14-pin-header |
| 25 | internal (I2S) | DSIN | |
| 26 | internal (I2S) | LRC | |
| 27 | internal (I2S) | BCLK | |
| 32 | internal (I2C) | CLK | |
| 33 | internal (I2C) | DATA | |
| 34 | internal (SD) | DETECT | To detect if SD is present (not used) |
| 35 | internal (I2S) | DOUT | |
| 36 | internal (Key) | A/D | Analog read for keys 1-6 or digial read for only key 1 |
| 39 | internal (HP) | DETECT | Detects if headphone is plugged in |

Now, question is what to do with GPIO22. Could be used to externally connect keys for analogRead() via voltage-dividers.

## Power-consumption
* IDLE: 105 mA
* Deepsleep (without RFID + Neopixel): 30 mA

## Things to consider
* I didn't battery-power this board (guess it works but didn't test). But as current in deepsleep still is 30 mA, this probably doesn't make sense.
* When using a switch (instead of putting 'only' to deepsleep), GPIO 19 (power) could be omitted. Along with GPIO 22, these buttons could be used as buttons 'previous' and 'next'. Third button could be omitted by assigning short-press-action of rotary-encoder for 'pause/play'.
* In order to safe energy consider the unsolder LEDs.

## Please note
* This one is more or less a project to test whether it's possible to run my fork on this special board. It's not really maintained actively but feel free to contact me in case of questions.
* Some additional informations regarding this board can be found [here](https://www.mikrocontroller.net/topic/474383?goto=6429727) and [here] (https://www.mikrocontroller.net/topic/492149).
* I discovered RFID.RST is uninportant. So you need to initialize it but doesn't matter whether it's connected or not. So I used just anything.

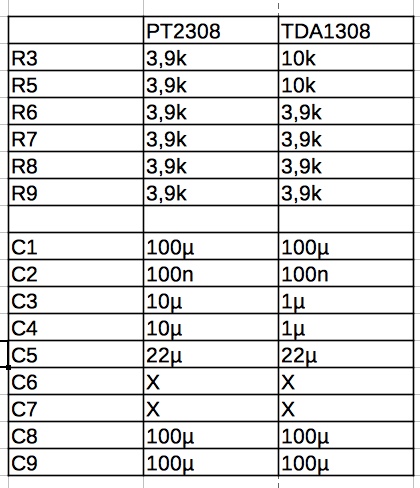
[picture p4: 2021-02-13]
PCBs/Headphone with PCM5102a and TDA1308/KiCad/Element list.jpeg

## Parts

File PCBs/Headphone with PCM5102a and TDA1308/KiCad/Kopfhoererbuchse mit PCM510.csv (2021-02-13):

ID | Bezeichner | Geh+AOQ-use | St | Bezeichnung
1 | IC1 | SOT95P282X145+AC0-5N | 1 | ME6211C33M5G
2 | +ACI-C19 | C18 | C4 | C3+ACI- | C+AF8-0603+AF8-1608Metric+AF8-Pad1.05x0.95mm+AF8-HandSolder | 4 | 1+ALU-
3 | JP1 | SolderJumper+AC0-2+AF8-P1.3mm+AF8-Open+AF8-Pad1.0x1.5mm | 1 | SolderJumper+AF8-2+AF8-Open
4 | Q1 | SOT+AC0-23 | 1 | IRLML6401
5 | J1 | PinHeader+AF8-2x03+AF8-P2.54mm+AF8-Vertical+AF8-large | 1 | Conn+AF8-02x03+AF8-Odd+AF8-Even
6 | U2 | SO+AC0-8+AF8-5.3x6.2mm+AF8-P1.27mm | 1 | TDA1308
7 | U1 | TSSOP+AC0-20+AF8-4.4x6.5mm+AF8-P0.65mm | 1 | PCM5102A
8 | +ACI-R15 | R14 | R13 | R11 | R10+ACI- | R+AF8-0805+AF8-2012Metric+AF8-Pad1.15x1.40mm+AF8-HandSolder | 5 | 470R
9 | +ACI-R12 | R5 | R3 | R2+ACI- | R+AF8-0805+AF8-2012Metric+AF8-Pad1.15x1.40mm+AF8-HandSolder | 4 | 10k
10 | +ACI-C17 | C16 | C14 | C12 | C2+ACI- | C+AF8-0603+AF8-1608Metric+AF8-Pad1.05x0.95mm+AF8-HandSolder | 5 | 100n
11 | +ACI-C15 | C13+ACI- | C+AF8-0603+AF8-1608Metric+AF8-Pad1.05x0.95mm+AF8-HandSolder | 2 | +ACI-2 | 2+ALU-+ACI-
12 | +ACI-C11 | C10+ACI- | C+AF8-0603+AF8-1608Metric+AF8-Pad1.05x0.95mm+AF8-HandSolder | 2 | +ACI-2 | 2n+ACI-
13 | J2 | Jack+AF8-3.5mm+AF8-Cliff+AF8-Horizontal | 1 | AudioJack3+AF8-Dual+AF8-Switch
14 | +ACI-H2 | H1+ACI- | MountingHole+AF8-3.2mm+AF8-M3 | 2 | MountingHole
15 | +ACI-R9 | R8 | R7 | R6+ACI- | R+AF8-0805+AF8-2012Metric+AF8-Pad1.15x1.40mm+AF8-HandSolder | 4 | +ACI-3 | 9k+ACI-
16 | R4 | R+AF8-0805+AF8-2012Metric+AF8-Pad1.15x1.40mm+AF8-HandSolder | 1 | 100k
17 | +ACI-C9 | C8 | C1+ACI- | CP+AF8-Radial+AF8-D6.3mm+AF8-P2.50mm | 3 | 100+ALU-
18 | C5 | CP+AF8-Radial+AF8-D4.0mm+AF8-P1.50mm | 1 | 22+ALU-
1 | L1 | L+AF8-Bourns+AF8-SRN6045TA+AF8-1 | 1 | INDUCTOR
2 | U3 | TSSOP+AC0-8+AF8-4.4x3mm+AF8-P0.65mm | 1 | L6920
3 | +ACI-JP3 | JP2+ACI- | SolderJumper+AC0-3+AF8-P1.3mm+AF8-Bridged2Bar12+AF8-Pad1.0x1.5mm+AF8-NumberLabels | 2 | +ACI-3 | 3 or 5V for DAC+ACI-
4 | U1 | Lolin+AF8-D32+AF8-PRO | 1 | LolinD32Pro
5 | J3 | PinHeader+AF8-1x02+AF8-P2.54mm+AF8-Vertical | 1 | LS
6 | J6 | PinHeader+AF8-2x03+AF8-P2.54mm+AF8-Vertical+AF8-large | 1 | Res+AF8-DAC
7 | R1 | R+AF8-0805+AF8-2012Metric+AF8-Pad1.15x1.40mm+AF8-HandSolder | 1 | 10k
8 | J8 | PinHeader+AF8-1x01+AF8-P2.54mm+AF8-Vertical | 1
9 | J5 | PinHeader+AF8-1x01+AF8-P2.54mm+AF8-Vertical | 1 | GND
10 | C7 | C+AF8-1210+AF8-3225Metric+AF8-Pad1.42x2.65mm+AF8-HandSolder | 1 | ca.1+ALU-
11 | +ACI-C6 | C4+ACI- | CP+AF8-Radial+AF8-D6.3mm+AF8-P2.50mm | 2 | 47+ALU-
12 | +ACI-C5 | C1+ACI- | C+AF8-0603+AF8-1608Metric+AF8-Pad1.05x0.95mm+AF8-HandSolder | 2 | 100n
13 | JP1 | SolderJumper+AC0-3+AF8-P1.3mm+AF8-Bridged2Bar12+AF8-Pad1.0x1.5mm+AF8-NumberLabels | 1 | +ACI-3 | 3 or 5V for LED+ACI-
14 | +ACI-H4 | H3 | H2 | H1+ACI- | MountingHole+AF8-3.2mm+AF8-M3 | 4 | MountingHole
15 | J7 | PinHeader+AF8-1x03+AF8-P2.54mm+AF8-Vertical | 1 | ChargeLED
16 | U4 | MAX98357A | 1 | MAX98357A
17 | J10 | PinHeader+AF8-1x03+AF8-P2.54mm+AF8-Vertical | 1 | RGB+AF8-LED
18 | J4 | PinHeader+AF8-1x08+AF8-P2.54mm+AF8-Vertical | 1 | RC+AC0-522
19 | J2 | PinHeader+AF8-1x05+AF8-P2.54mm+AF8-Vertical | 1 | Rotary
20 | J1 | PinHeader+AF8-1x04+AF8-P2.54mm+AF8-Vertical | 1 | Keys
21 | R2 | R+AF8-0805+AF8-2012Metric+AF8-Pad1.15x1.40mm+AF8-HandSolder | 1 | 10K
22 | C2 | C+AF8-0603+AF8-1608Metric+AF8-Pad1.05x0.95mm+AF8-HandSolder | 1 | C+AF8-ONT+AF8-22n
23 | U2 | SOT+AC0-23+AC0-8+AF8-Handsoldering | 1 | LTC2954+AC0-1
24 | R3 | R+AF8-0805+AF8-2012Metric+AF8-Pad1.15x1.40mm+AF8-HandSolder | 1 | 1K
25 | +ACI-R4 | R5+ACI- | R+AF8-0805+AF8-2012Metric+AF8-Pad1.15x1.40mm+AF8-HandSolder | 2 | 100K
26 | F1 | Fuse+AF8-1206+AF8-3216Metric+AF8-Pad1.42x1.75mm+AF8-HandSolder | 1 | Polyfuse
27 | C3 | C+AF8-0603+AF8-1608Metric+AF8-Pad1.05x0.95mm+AF8-HandSolder | 1 | C+AF8-PDT+AF8-47n
28 | Q1 | SOT+AC0-23 | 1 | IRLML2502

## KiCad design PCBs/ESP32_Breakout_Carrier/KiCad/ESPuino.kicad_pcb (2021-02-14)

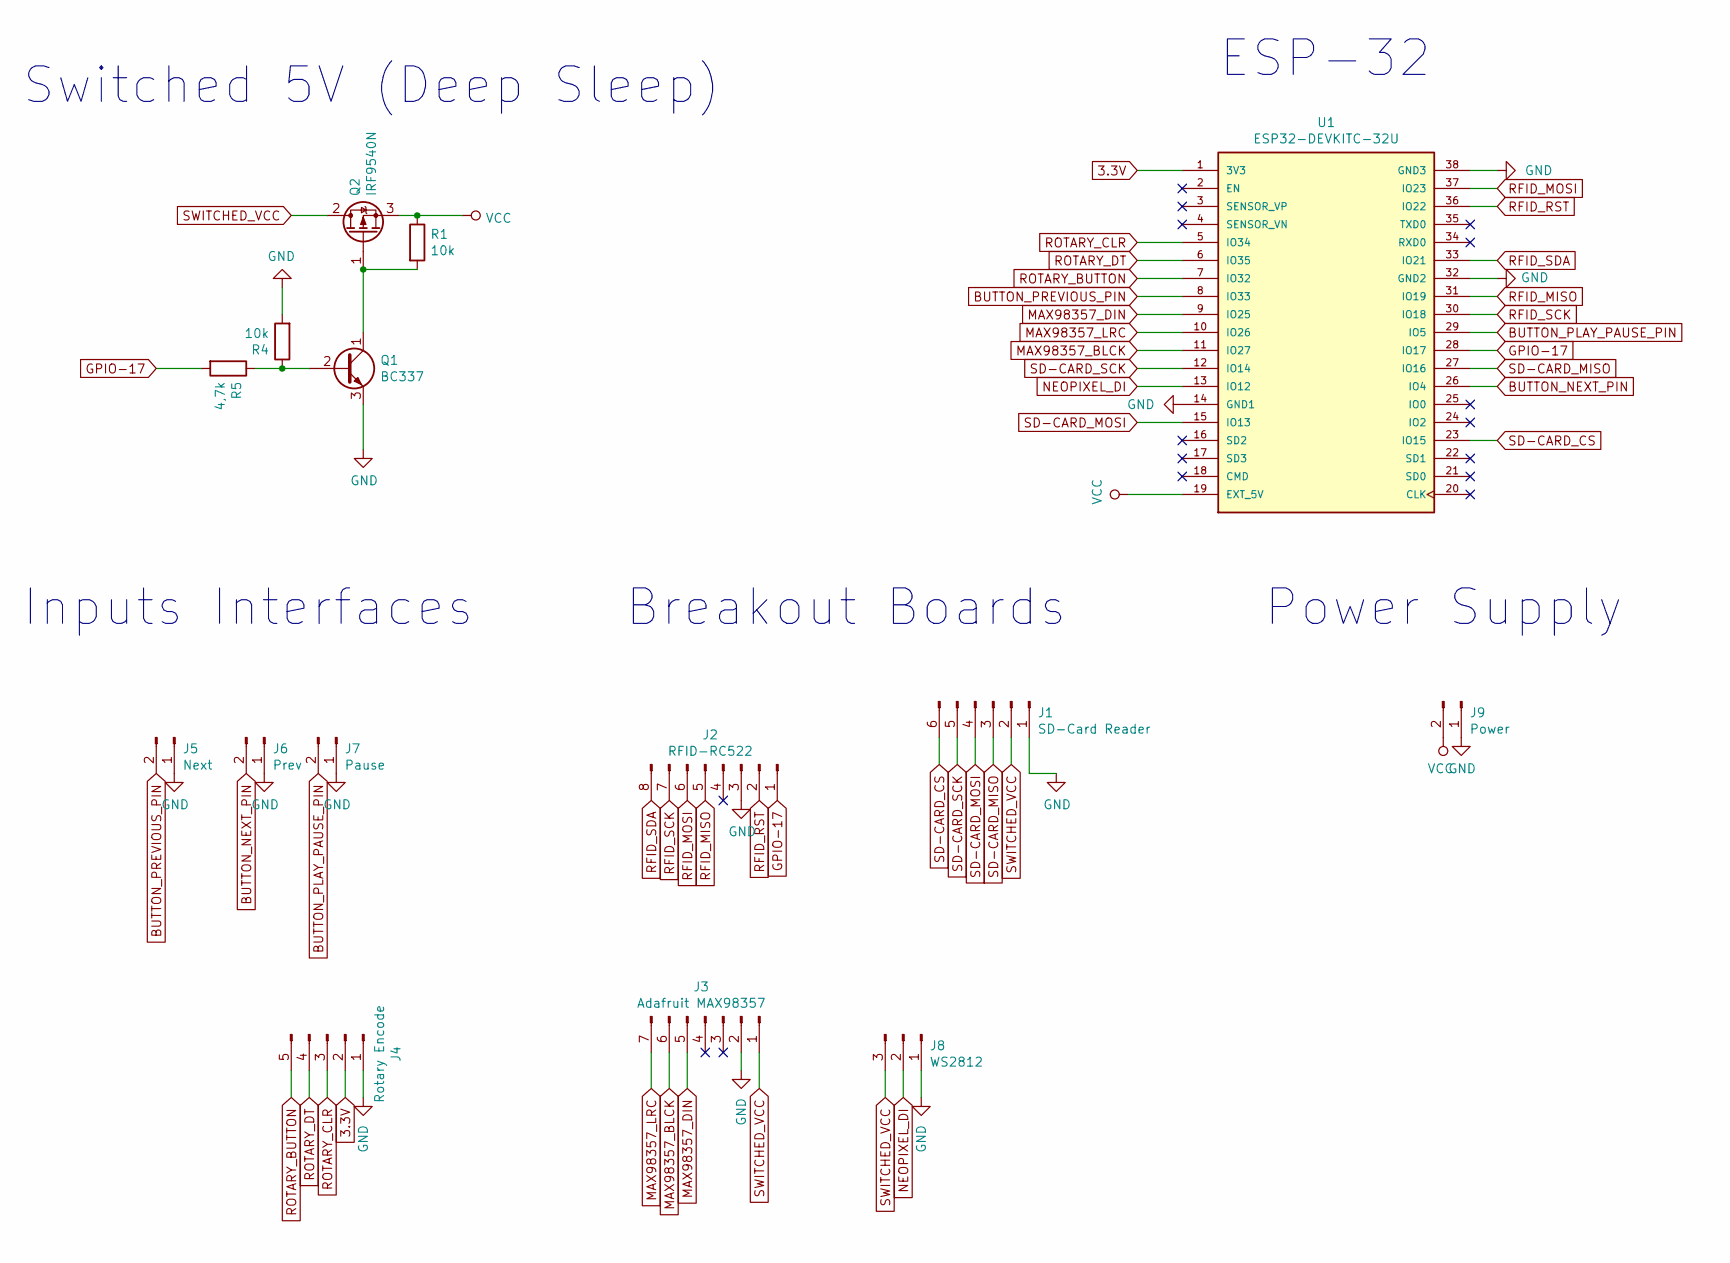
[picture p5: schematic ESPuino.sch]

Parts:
J1: SD-Card Reader; PinHeader_1x06_P2.54mm_Vertical
J2: RFID-RC522; PinHeader_1x08_P2.54mm_Vertical
J3: Adafruit MAX98357; PinHeader_1x07_P2.54mm_Vertical
J4: Rotary Encode; PinHeader_1x05_P2.54mm_Vertical
J5: Next; PinHeader_1x02_P2.54mm_Vertical
J6: Prev; PinHeader_1x02_P2.54mm_Vertical
J7: Pause; PinHeader_1x02_P2.54mm_Vertical
J8: WS2812; PinHeader_1x03_P2.54mm_Vertical
J9: Power; PinHeader_1x02_P2.54mm_Vertical
Q1: BC337; TO-92_Inline_Wide
Q2: IRF9540N; TO-220-3_Vertical
R1, R4: 10k; 0207_9
R5: 4,7k; 0207_9
U1: ESP32-DEVKITC-32U; MODULE_ESP32-DEVKITC-32U; PARTREV N/A

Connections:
3.3V: J4.2, U1.1 (3V3)
BUTTON_NEXT_PIN: J6.2, U1.26 (IO4)
BUTTON_PLAY_PAUSE_PIN: J7.2, U1.29 (IO5)
BUTTON_PREVIOUS_PIN: J5.2, U1.8 (IO33)
GND: J1.1, J2.3, J3.2, J4.1, J5.1, J6.1, J7.1, J8.1, J9.1, Q1.3 (E), R4.2, U1.14 (GND1), U1.32 (GND2), U1.38 (GND3)
GPIO-17: J2.1, R5.2, U1.28 (IO17)
MAX98357_BLCK: J3.6, U1.11 (IO27)
MAX98357_DIN: J3.5, U1.9 (IO25)
MAX98357_LRC: J3.7, U1.10 (IO26)
NEOPIXEL_DI: J8.2, U1.13 (IO12)
unnamed: Q1.1 (C), Q2.1 (G), R1.2
unnamed: Q1.2 (B), R4.1, R5.1
RFID_MISO: J2.5, U1.31 (IO19)
RFID_MOSI: J2.6, U1.37 (IO23)
RFID_RST: J2.2, U1.36 (IO22)
RFID_SCK: J2.7, U1.30 (IO18)
RFID_SDA: J2.8, U1.33 (IO21)
ROTARY_BUTTON: J4.5, U1.7 (IO32)
ROTARY_CLR: J4.3, U1.5 (IO34)
ROTARY_DT: J4.4, U1.6 (IO35)
SD-CARD_CS: J1.6, U1.23 (IO15)
SD-CARD_MISO: J1.3, U1.27 (IO16)
SD-CARD_MOSI: J1.4, U1.15 (IO13)
SD-CARD_SCK: J1.5, U1.12 (IO14)
SWITCHED_VCC: J1.2, J3.1, J8.3, Q2.2 (D)
VCC: J9.2, Q2.3 (S), R1.1, U1.19 (EXT_5V)

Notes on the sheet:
Breakout Boards
Inputs Interfaces
Switched 5V (Deep Sleep)
ESP-32
Power Supply

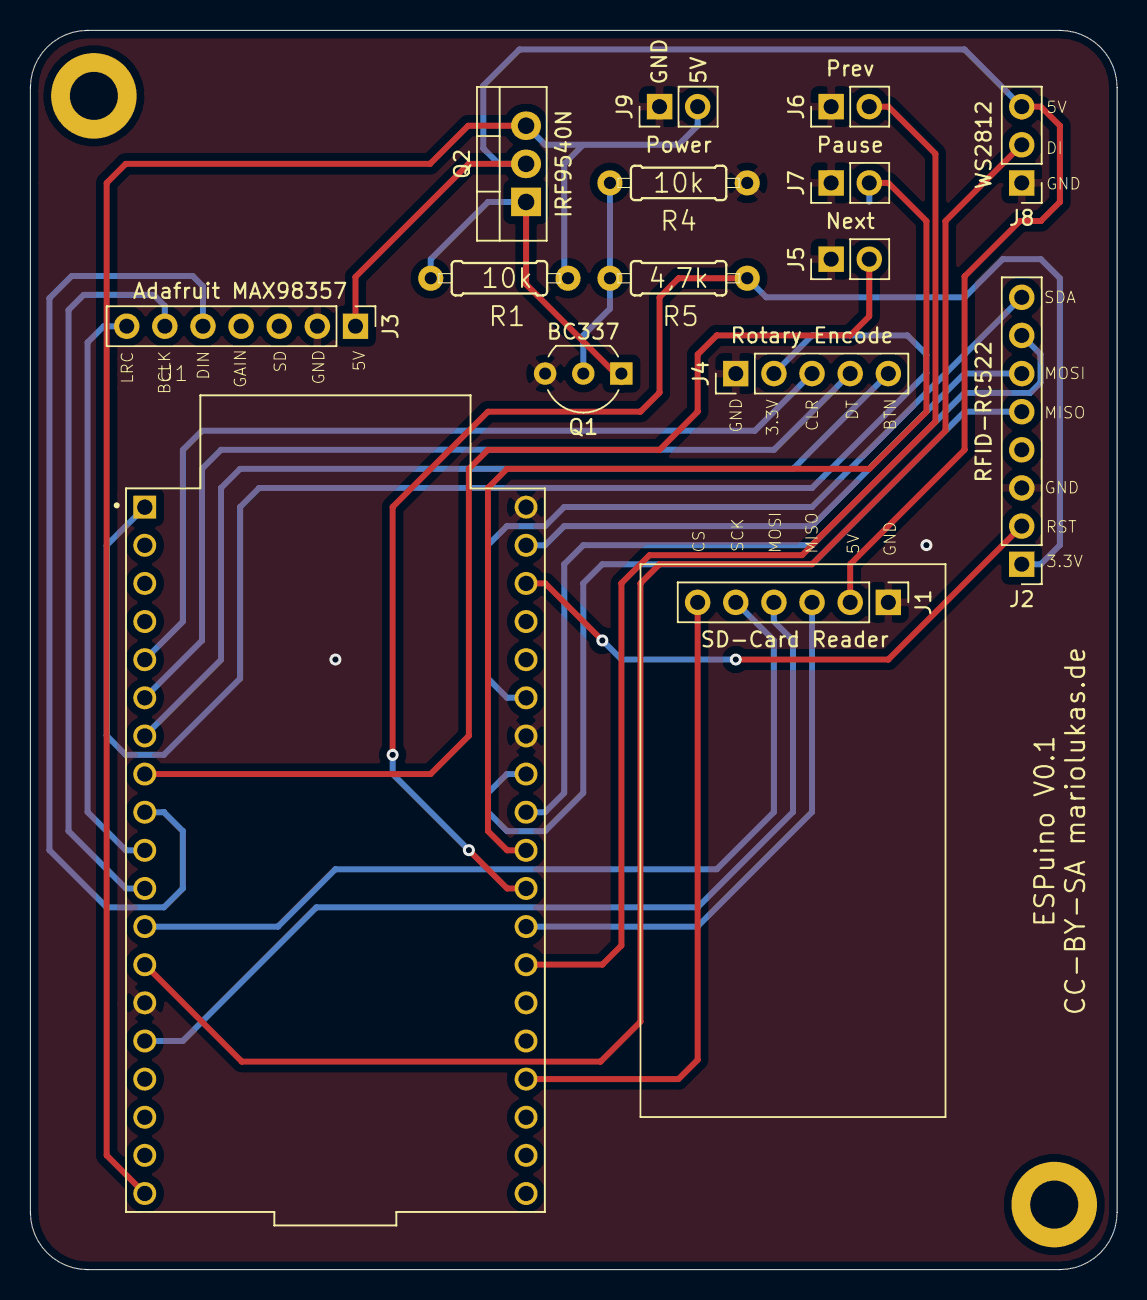
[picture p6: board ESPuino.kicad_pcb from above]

Board: 2 copper layers, 72.4 x 82.6 mm, 15 parts (0 on the bottom side), 26 nets.

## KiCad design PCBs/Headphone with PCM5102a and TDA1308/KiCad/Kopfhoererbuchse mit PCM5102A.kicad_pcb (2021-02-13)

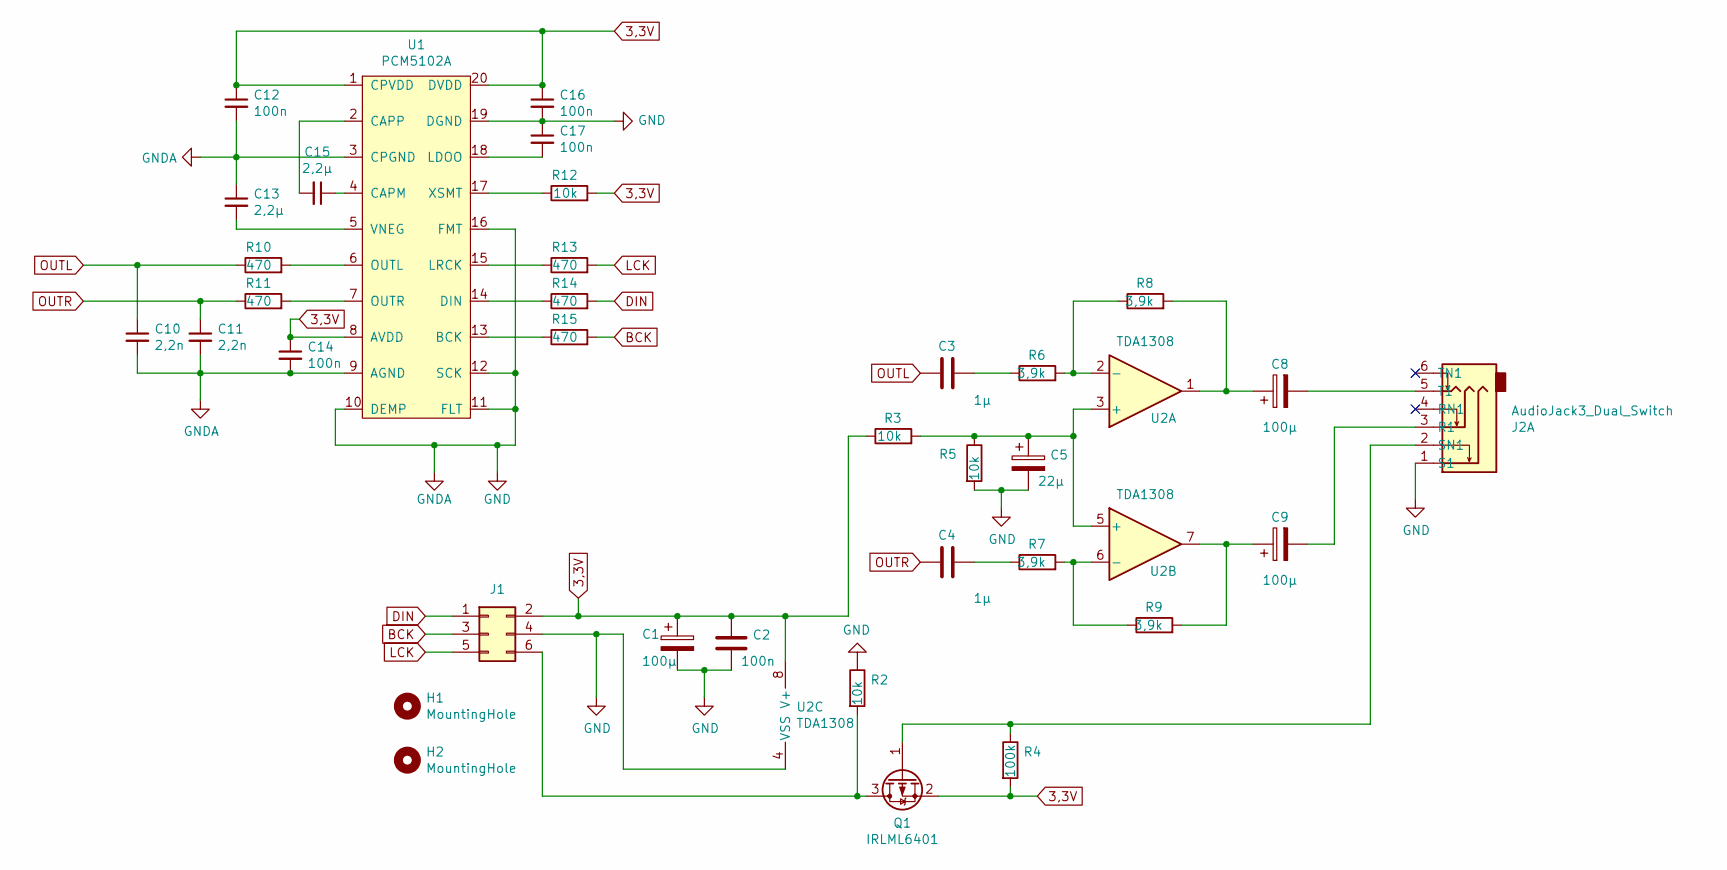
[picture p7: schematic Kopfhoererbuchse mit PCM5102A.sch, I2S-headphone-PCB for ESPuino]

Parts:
C1, C8, C9: 100µ; CP_Radial_D6.3mm_P2.50mm
C2, C12, C14, C16, C17: 100n; C_0603_1608Metric_Pad1.05x0.95mm_HandSolder
C3, C4: 1µ; C_0603_1608Metric_Pad1.05x0.95mm_HandSolder
C5: 22µ; CP_Radial_D4.0mm_P1.50mm
C10, C11: 2,2n; C_0603_1608Metric_Pad1.05x0.95mm_HandSolder
C13, C15: 2,2µ; C_0603_1608Metric_Pad1.05x0.95mm_HandSolder
H1, H2: MountingHole; MountingHole_3.2mm_M3
J1: Conn_02x03_Odd_Even; PinHeader_2x03_P2.54mm_Vertical_large
J2: AudioJack3_Dual_Switch; Jack_3.5mm_Cliff_Horizontal
Q1: IRLML6401; SOT-23
R2, R3, R5, R12: 10k; R_0805_2012Metric_Pad1.15x1.40mm_HandSolder
R4: 100k; R_0805_2012Metric_Pad1.15x1.40mm_HandSolder
R6, R7, R8, R9: 3,9k; R_0805_2012Metric_Pad1.15x1.40mm_HandSolder
R10, R11, R13, R14, R15: 470; R_0805_2012Metric_Pad1.15x1.40mm_HandSolder
U1: PCM5102A; TSSOP-20_4.4x6.5mm_P0.65mm
U2: TDA1308; SO-8_5.3x6.2mm_P1.27mm

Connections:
3,3V: C1.1, C2.1, C12.1, C14.1, C16.1, J1.2, Q1.2 (S), R3.1, R4.2, R12.2, U1.1 (CPVDD), U1.8 (AVDD), U1.20 (DVDD), U2.8 (V+)
BCK: J1.3, R15.2
DIN: J1.1, R14.2
GND: C1.2, C2.2, C5.2, C10.2, C11.2, C12.2, C13.1, C14.2, C16.2, C17.1, J1.4, J2.1 (S1), R2.1, R5.2, U1.3 (CPGND), U1.9 (AGND), U1.10 (DEMP), U1.11 (FLT), U1.12 (SCK), U1.16 (FMT), U1.19 (DGND), U2.4 (VSS)
LCK: J1.5, R13.2
unnamed: C3.2, R6.1
unnamed: C4.2, R7.1
unnamed: C5.1, R3.2, R5.1, U2.3 (+), U2.5 (+)
unnamed: C8.1, R8.2, U2.1
unnamed: C8.2, J2.5 (T1)
unnamed: C9.1, R9.2, U2.7
unnamed: C9.2, J2.3 (R1)
unnamed: C13.2, U1.5 (VNEG)
unnamed: C15.1, U1.4 (CAPM)
unnamed: C15.2, U1.2 (CAPP)
unnamed: C17.2, U1.18 (LDOO)
unnamed: J1.6, Q1.3 (D), R2.2
unnamed: J2.2 (SN1), Q1.1 (G), R4.1
unnamed: R6.2, R8.1, U2.2 (-)
unnamed: R7.2, R9.1, U2.6 (-)
unnamed: R10.2, U1.6 (OUTL)
unnamed: R11.2, U1.7 (OUTR)
unnamed: R12.1, U1.17 (XSMT)
unnamed: R13.1, U1.15 (LRCK)
unnamed: R14.1, U1.14 (DIN)
unnamed: R15.1, U1.13 (BCK)
OUTL: C3.1, C10.1, R10.1
OUTR: C4.1, C11.1, R11.1

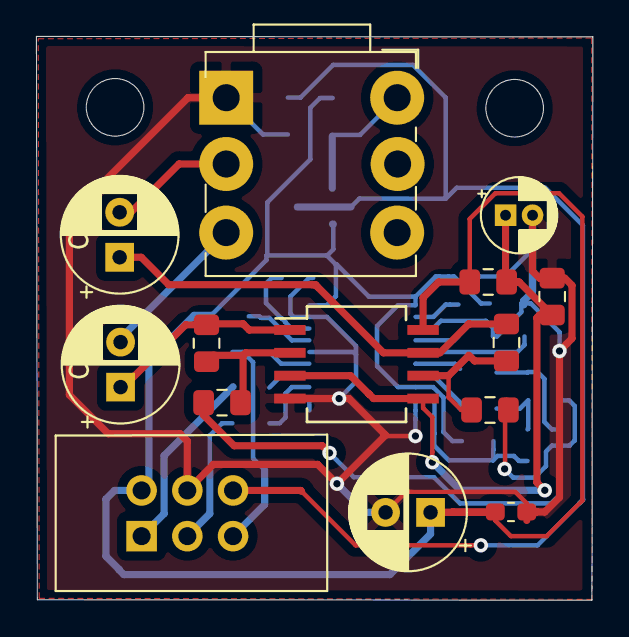
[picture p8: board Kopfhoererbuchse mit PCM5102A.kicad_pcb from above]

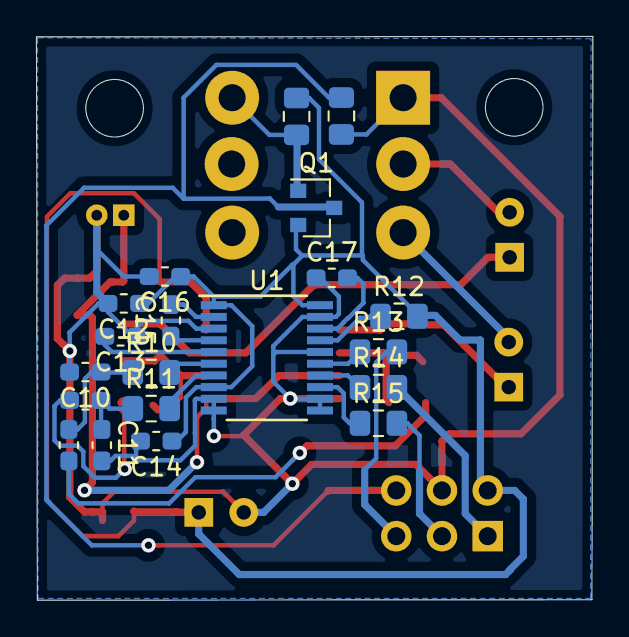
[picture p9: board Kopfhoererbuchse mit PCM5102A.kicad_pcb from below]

Board: 2 copper layers, 30.9 x 31.3 mm, 36 parts (20 on the bottom side), 28 nets.

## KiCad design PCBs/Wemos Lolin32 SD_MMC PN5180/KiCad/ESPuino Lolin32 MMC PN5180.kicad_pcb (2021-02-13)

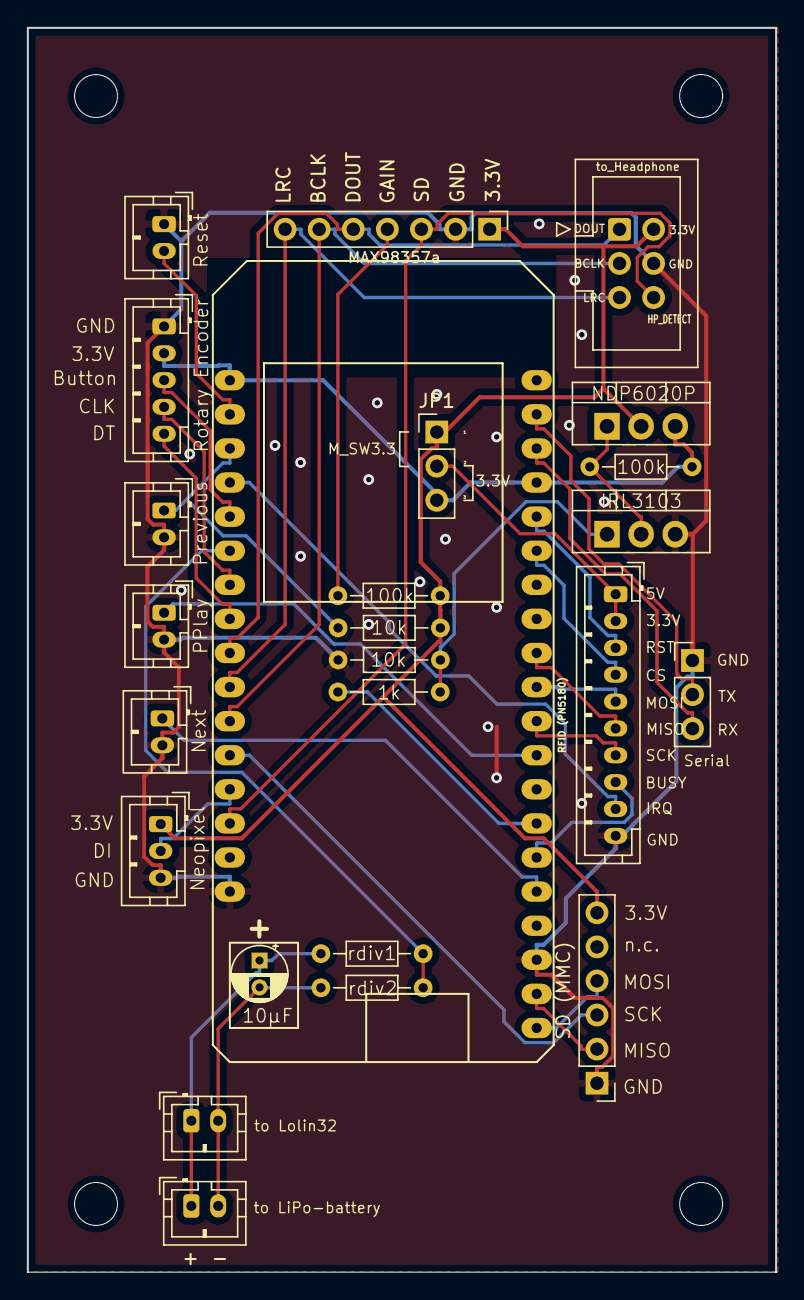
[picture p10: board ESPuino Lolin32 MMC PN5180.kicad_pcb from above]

Board: 2 copper layers, 55.8 x 92.7 mm, 29 parts (0 on the bottom side), 35 nets.

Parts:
C1: 10µF; CP_Radial_D4.0mm_P2.00mm
H1, H2, H3, H4: MountingHole; MountingHole_3.2mm_M3
J1: to LiPo-battery; JST_PH_B2B-PH-K_1x02_P2.00mm_Vertical
J2: to Lolin; JST_PH_B2B-PH-K_1x02_P2.00mm_Vertical
J3: to_Headphone; IDC-Header_2x03_P2.54mm_Vertical
J4: MAX98357a; PinHeader_1x07_P2.54mm_Vertical
J5: Neopixel; JST_PH_B3B-PH-K_1x03_P2.00mm_Vertical
J6: Rotary Encoder; JST_PH_B5B-PH-K_1x05_P2.00mm_Vertical
J7: RFID (PN5180); JST_PH_B10B-PH-K_1x10_P2.00mm_Vertical
J8: Reset; JST_PH_B2B-PH-K_1x02_P2.00mm_Vertical
J9: Next; JST_PH_B2B-PH-K_1x02_P2.00mm_Vertical
J10: Previous; JST_PH_B2B-PH-K_1x02_P2.00mm_Vertical
J11: PPlay; JST_PH_B2B-PH-K_1x02_P2.00mm_Vertical
J12: SD (MMC); PinHeader_1x06_P2.54mm_Vertical
J13: Serial; PinHeader_1x03_P2.54mm_Vertical
JP1: Jumper_NC_Dual; PinHeader_1x03_P2.54mm_Vertical
Q1: IRL3103; TO-220-3_Vertical
Q2: NDP6020P; TO-220-3_Vertical
R1: rdiv1; R_Axial_DIN0204_L3.6mm_D1.6mm_P7.62mm_Horizontal
R2: rdiv2; R_Axial_DIN0204_L3.6mm_D1.6mm_P7.62mm_Horizontal
R3, R6: 100k; R_Axial_DIN0204_L3.6mm_D1.6mm_P7.62mm_Horizontal
R4: 1k; R_Axial_DIN0204_L3.6mm_D1.6mm_P7.62mm_Horizontal
R5, R7: 10k; R_Axial_DIN0204_L3.6mm_D1.6mm_P7.62mm_Horizontal
U1: Lolin32

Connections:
+3V3: J6.2, JP1.3, Q2.3, R6.2, U1.1, U1.20
BUT_NEXT: J9.1, U1.32
BUT_PPLAY: J11.1, U1.28
BUT_PREV: J10.1, R7.1, U1.3
EN: J8.2, U1.2
GND: J3.4, J4.2, J5.3, J6.1, J7.10, J8.1, J9.2, J10.2, J11.2, J12.1, J13.1, Q1.3, R5.1, U1.16, U1.34
HEADPHONE: J3.6, J4.3, U1.14
I2S_BCLK: J3.3, J4.6, U1.11
I2S_DOUT: J3.1, J4.5, U1.9
I2S_LRC: J3.5, J4.7, U1.10
MMC_MISO: J12.2, U1.35
MMC_MOSI: J12.4, U1.36
MMC_SCK: J12.3, U1.12
NEOPIXEL: J5.2, U1.13
unnamed: C1.1, J1.1, J2.1, R1.2
unnamed: C1.2, J1.2, J2.2, R2.2
unnamed: J4.4, R3.1
unnamed: J7.1, J7.2, JP1.2
unnamed: Q1.1, R4.1, R5.2
unnamed: Q1.2, Q2.1, R6.1
unnamed: R4.2, U1.30
RFID_BUSY: J7.8, U1.31
RFID_CS: J7.4, U1.22
RFID_IRQ: J7.9, U1.4
RFID_MISO: J7.6, U1.25
RFID_MOSI: J7.5, U1.26
RFID_RST: J7.3, U1.21
RFID_SCK: J7.7, U1.27
ROTENC_BUT: J6.3, U1.5
ROTENC_CLK: J6.4, U1.7
ROTENC_DT: J6.5, U1.8
RX: J13.3, U1.19
SW_POWER3.3: J3.2, J4.1, J5.1, J12.6, JP1.1, Q2.2, R3.2, R7.2
TX: J13.2, U1.18
VBAT: R1.1, R2.1, U1.6

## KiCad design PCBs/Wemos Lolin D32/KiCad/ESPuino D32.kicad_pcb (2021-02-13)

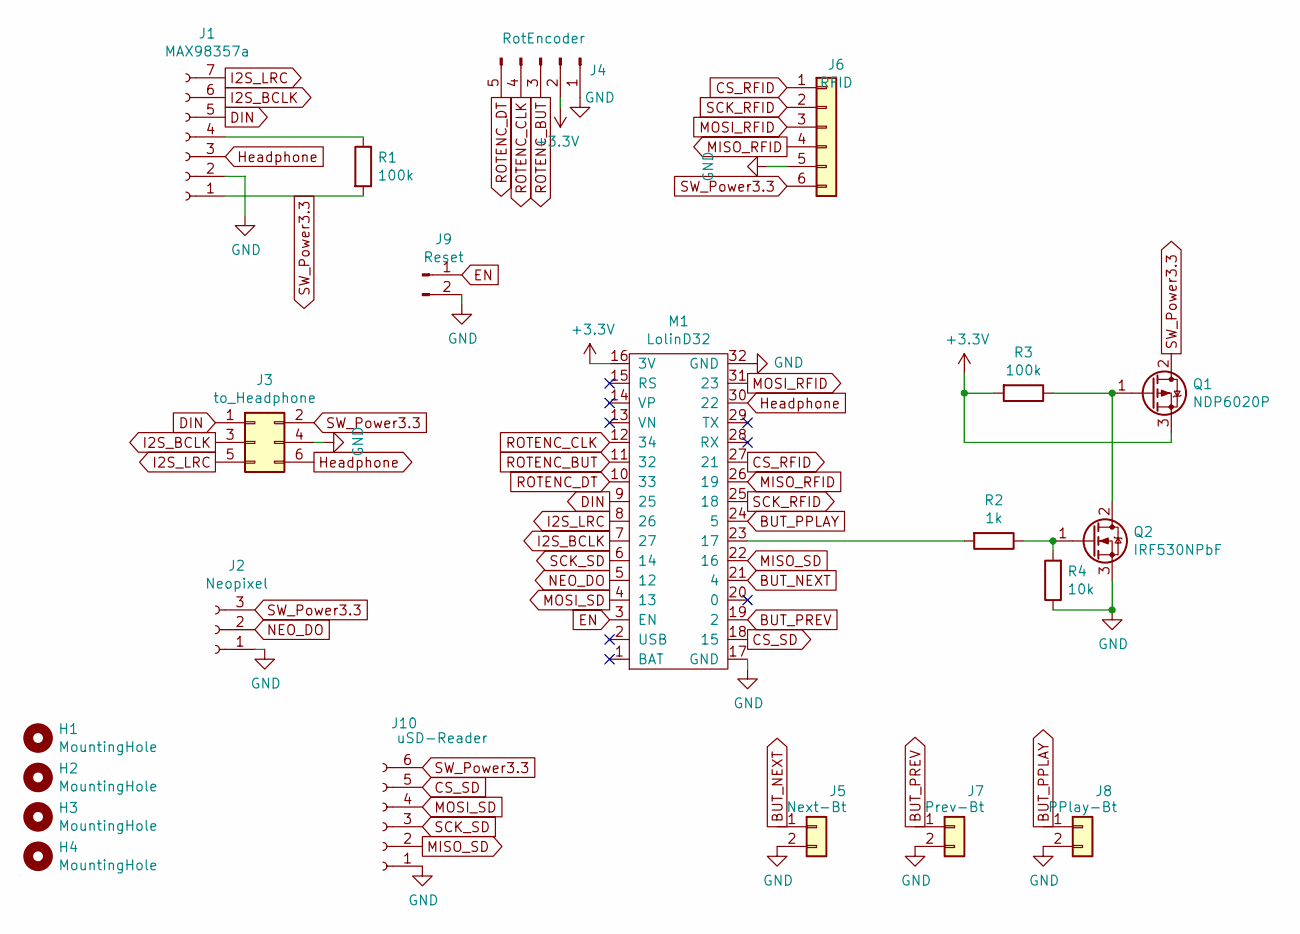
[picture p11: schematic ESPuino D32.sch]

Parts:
H1, H2, H3, H4: MountingHole; MountingHole_3.2mm_M3
J1: MAX98357a; PinSocket_1x07_P2.54mm_Vertical
J2: Neopixel; JST_PH_B3B-PH-K_1x03_P2.00mm_Vertical
J3: to_Headphone; IDC-Header_2x03_P2.54mm_Vertical
J4: RotEncoder; JST_PH_B5B-PH-K_1x05_P2.00mm_Vertical
J5: Next-Bt; JST_PH_B2B-PH-K_1x02_P2.00mm_Vertical
J6: RFID; JST_PH_B6B-PH-K_1x06_P2.00mm_Vertical
J7: Prev-Bt; JST_PH_B2B-PH-K_1x02_P2.00mm_Vertical
J8: PPlay-Bt; JST_PH_B2B-PH-K_1x02_P2.00mm_Vertical
J9: Reset; JST_PH_B2B-PH-K_1x02_P2.00mm_Vertical
J10: uSD-Reader; PinSocket_1x06_P2.54mm_Vertical
M1: LolinD32
Q1: NDP6020P; TO-220-3_Vertical
Q2: IRF530NPbF; TO-220-3_Vertical
R1, R3: 100k; R_Axial_DIN0204_L3.6mm_D1.6mm_P7.62mm_Horizontal
R2: 1k; R_Axial_DIN0204_L3.6mm_D1.6mm_P7.62mm_Horizontal
R4: 10k; R_Axial_DIN0204_L3.6mm_D1.6mm_P7.62mm_Horizontal

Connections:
+3V3: J4.2, M1.16 (3V), Q1.3 (S), R3.2
BUT_NEXT: J5.1, M1.21 (4)
BUT_PPLAY: J8.1, M1.24 (5)
BUT_PREV: J7.1, M1.19 (2)
CS_RFID: J6.1, M1.27 (21)
CS_SD: J10.5, M1.18 (15)
DIN: J1.5, J3.1, M1.9 (25)
EN: J9.1, M1.3 (EN)
GND: J1.2, J2.1, J3.4, J4.1, J5.2, J6.5, J7.2, J8.2, J9.2, J10.1, M1.17 (GND), M1.32 (GND), Q2.3 (S), R4.1
Headphone: J1.3, J3.6, M1.30 (22)
I2S_BCLK: J1.6, J3.3, M1.7 (27)
I2S_LRC: J1.7, J3.5, M1.8 (26)
MISO_RFID: J6.4, M1.26 (19)
MISO_SD: J10.2, M1.22 (16)
MOSI_RFID: J6.3, M1.31 (23)
MOSI_SD: J10.4, M1.4 (13)
NEO_DO: J2.2, M1.5 (12)
unnamed: J1.4, R1.1
unnamed: M1.23 (17), R2.2
unnamed: Q1.1 (G), Q2.2 (D), R3.1
unnamed: Q2.1 (G), R2.1, R4.2
ROTENC_BUT: J4.3, M1.11 (32)
ROTENC_CLK: J4.4, M1.12 (34)
ROTENC_DT: J4.5, M1.10 (33)
SCK_RFID: J6.2, M1.25 (18)
SCK_SD: J10.3, M1.6 (14)
SW_Power3.3: J1.1, J2.3, J3.2, J6.6, J10.6, Q1.2 (D), R1.2

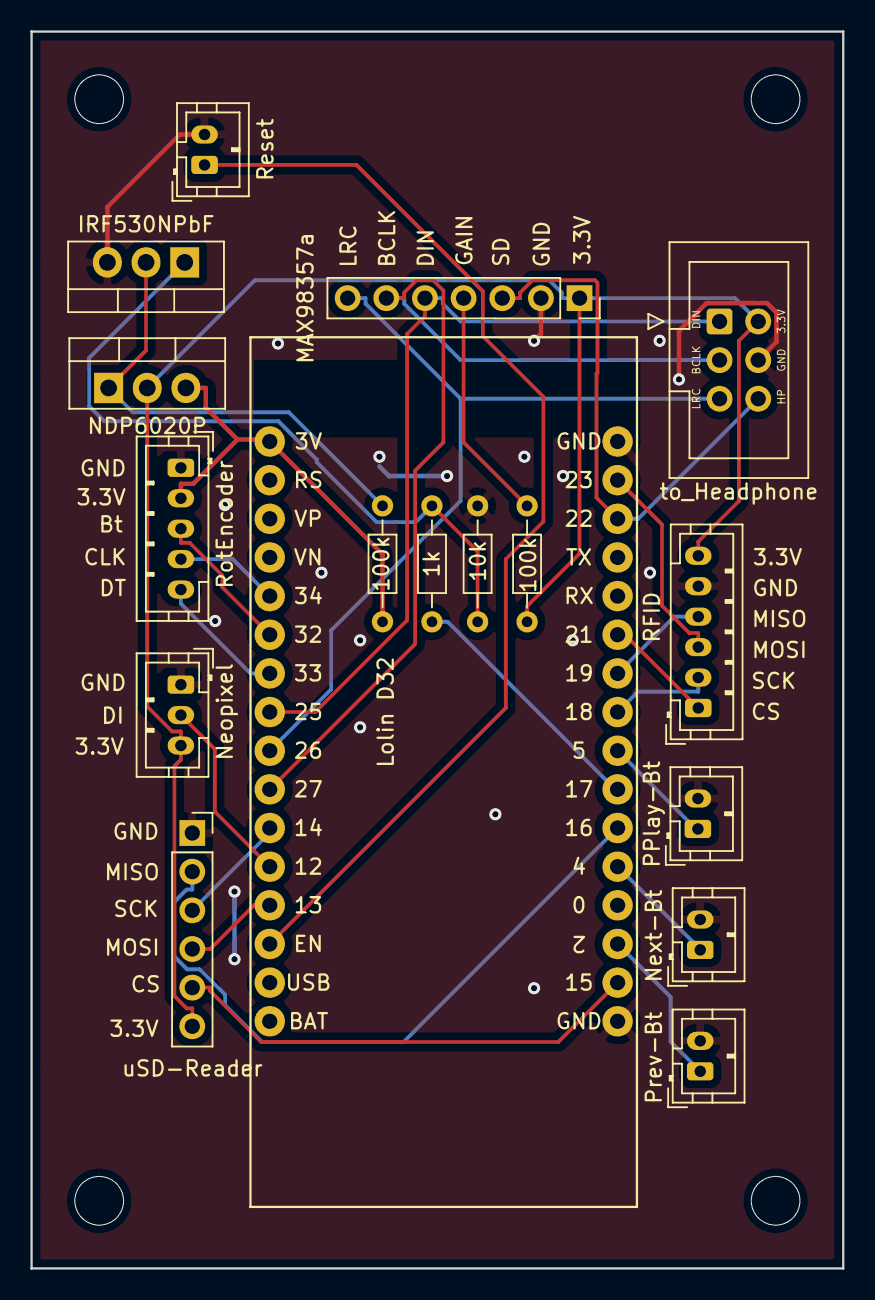
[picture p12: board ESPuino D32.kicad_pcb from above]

Board: 2 copper layers, 53.3 x 81.3 mm, 21 parts (0 on the bottom side), 27 nets.

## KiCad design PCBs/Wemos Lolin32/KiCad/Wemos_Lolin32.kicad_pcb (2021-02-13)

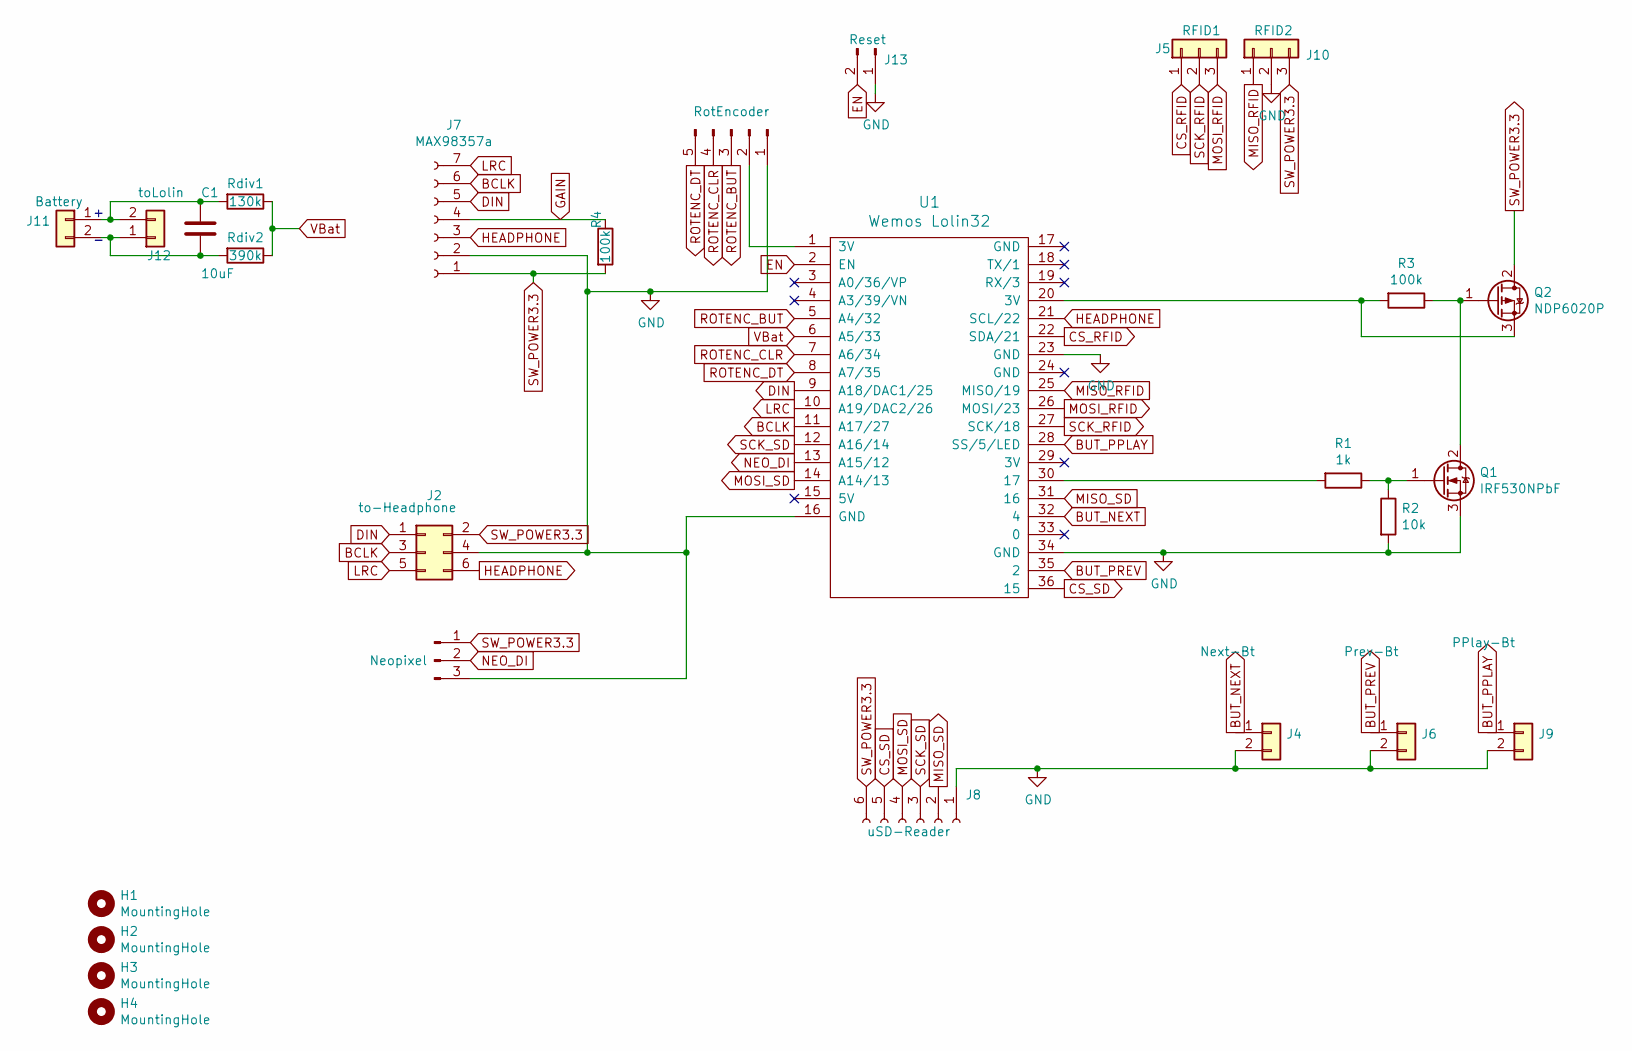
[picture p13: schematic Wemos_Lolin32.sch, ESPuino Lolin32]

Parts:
C1: 10uF; CP_Radial_D4.0mm_P2.00mm
H1, H2, H3, H4: MountingHole; MountingHole_3.2mm_M3
J1: Neopixel; JST_PH_B3B-PH-K_1x03_P2.00mm_Vertical
J2: to-Headphone; IDC-Header_2x03_P2.54mm_Vertical
J3: RotEncoder; JST_PH_B5B-PH-K_1x05_P2.00mm_Vertical
J4: Next-Bt; JST_PH_B2B-PH-K_1x02_P2.00mm_Vertical
J5: RFID1; JST_PH_B3B-PH-K_1x03_P2.00mm_Vertical
J6: Prev-Bt; JST_PH_B2B-PH-K_1x02_P2.00mm_Vertical
J7: MAX98357a; PinSocket_1x07_P2.54mm_Vertical
J8: uSD-Reader; PinSocket_1x06_P2.54mm_Vertical
J9: PPlay-Bt; JST_PH_B2B-PH-K_1x02_P2.00mm_Vertical
J10: RFID2; JST_PH_B3B-PH-K_1x03_P2.00mm_Vertical
J11: Battery; JST_PH_B2B-PH-K_1x02_P2.00mm_Vertical
J12: toLolin; PinHeader_1x02_P2.00mm_Vertical
J13: Reset; JST_PH_B2B-PH-K_1x02_P2.00mm_Vertical
Q1: IRF530NPbF; TO-220-3_Vertical
Q2: NDP6020P; TO-220-3_Vertical
R1: 1k; R_Axial_DIN0204_L3.6mm_D1.6mm_P7.62mm_Horizontal
R2: 10k; R_Axial_DIN0204_L3.6mm_D1.6mm_P7.62mm_Horizontal
R3, R4: 100k; R_Axial_DIN0204_L3.6mm_D1.6mm_P7.62mm_Horizontal
Rdiv1: 130k; R_Axial_DIN0204_L3.6mm_D1.6mm_P7.62mm_Horizontal
Rdiv2: 390k; R_Axial_DIN0204_L3.6mm_D1.6mm_P7.62mm_Horizontal
U1: Wemos Lolin32; Lolin32

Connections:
BCLK: J2.3, J7.6, U1.11 (A17/27)
BUT_NEXT: J4.1, U1.32 (4)
BUT_PPLAY: J9.1, U1.28 (SS/5/LED)
BUT_PREV: J6.1, U1.35 (2)
CS_RFID: J5.1, U1.22 (SDA/21)
CS_SD: J8.5, U1.36 (15)
DIN: J2.1, J7.5, U1.9 (A18/DAC1/25)
EN: J13.2, U1.2 (EN)
GAIN: J7.4, R4.1
GND: J1.3, J2.4, J3.1, J4.2, J6.2, J7.2, J8.1, J9.2, J10.2, J13.1, Q1.3 (S), R2.2, U1.16 (GND), U1.23 (GND), U1.34 (GND)
HEADPHONE: J2.6, J7.3, U1.21 (SCL/22)
LRC: J2.5, J7.7, U1.10 (A19/DAC2/26)
MISO_RFID: J10.1, U1.25 (MISO/19)
MISO_SD: J8.2, U1.31 (16)
MOSI_RFID: J5.3, U1.26 (MOSI/23)
MOSI_SD: J8.4, U1.14 (A14/13)
NEO_DI: J1.2, U1.13 (A15/12)
unnamed: C1.1, J11.1, J12.2, Rdiv1.2
unnamed: C1.2, J11.2, J12.1, Rdiv2.2
unnamed: J3.2, U1.1 (3V)
unnamed: Q1.1 (G), R1.1, R2.1
unnamed: Q1.2 (D), Q2.1 (G), R3.1
unnamed: Q2.3 (S), R3.2, U1.20 (3V)
unnamed: R1.2, U1.30 (17)
ROTENC_BUT: J3.3, U1.5 (A4/32)
ROTENC_CLR: J3.4, U1.7 (A6/34)
ROTENC_DT: J3.5, U1.8 (A7/35)
SCK_RFID: J5.2, U1.27 (SCK/18)
SCK_SD: J8.3, U1.12 (A16/14)
SW_POWER3.3: J1.1, J2.2, J7.1, J8.6, J10.3, Q2.2 (D), R4.2
VBat: Rdiv1.1, Rdiv2.1, U1.6 (A5/33)

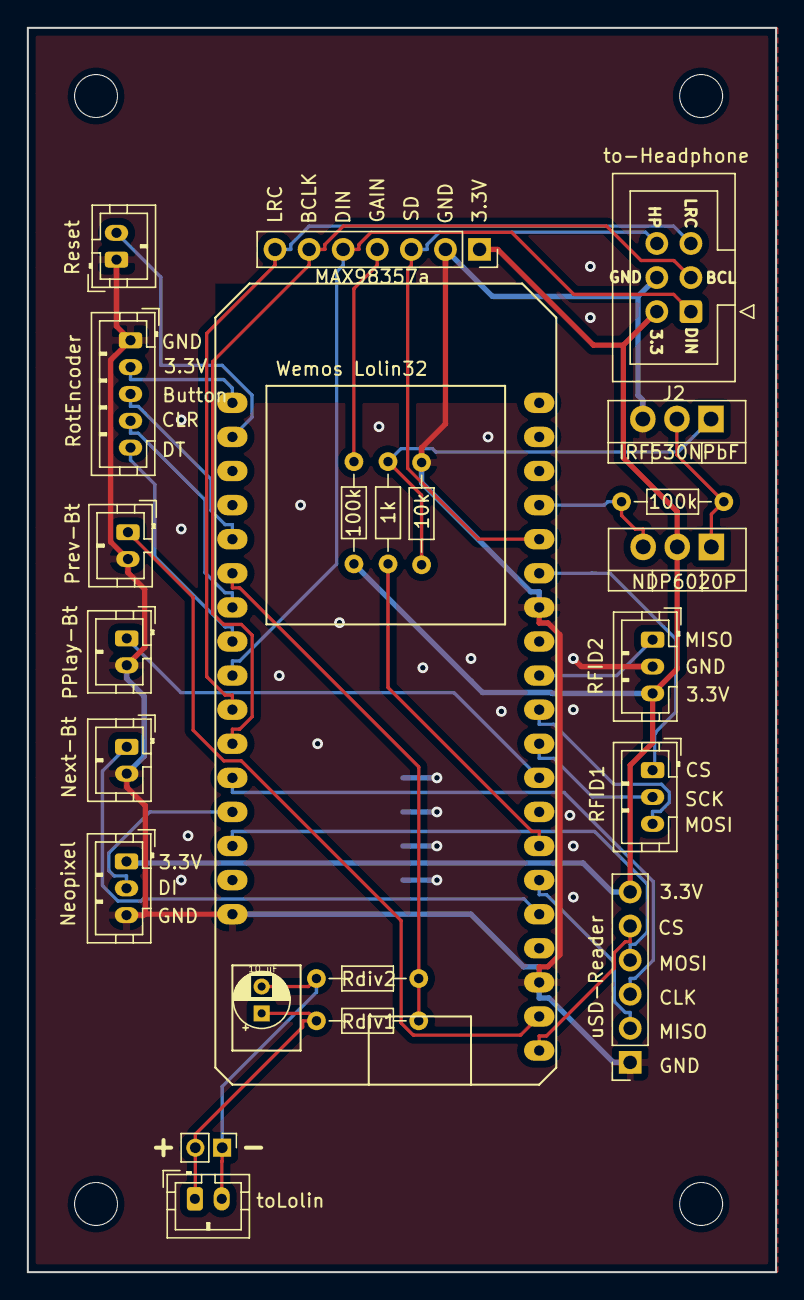
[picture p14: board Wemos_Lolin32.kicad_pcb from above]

Board: 2 copper layers, 55.8 x 92.7 mm, 27 parts (0 on the bottom side), 31 nets.

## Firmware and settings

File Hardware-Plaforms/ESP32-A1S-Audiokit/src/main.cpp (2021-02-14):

// Define modules to compile:
#define MQTT_ENABLE
#define FTP_ENABLE
#define NEOPIXEL_ENABLE             // Don't forget configuration of NUM_LEDS
#define NEOPIXEL_REVERSE_ROTATION   // Some Neopixels are adressed/soldered counter-clockwise. This can be configured here.
#define LANGUAGE 1                  // 1 = deutsch; 2 = english

#include <ESP32Encoder.h>
#include "Arduino.h"
#include <WiFi.h>
#ifdef FTP_ENABLE
    #include "ESP32FtpServer.h"
#endif
#include "Audio.h"
#include "AC101.h"
#include "SPI.h"
#include "SD.h"
#include "FS.h"
#include "esp_task_wdt.h"
#include <MFRC522.h>                // https://github.com/madias123/STM32duino-RFID-Mp3-Player/tree/master/3d%20party%20libraries%20(modified)/MFRC522
#include <Preferences.h>
#ifdef MQTT_ENABLE
    #include <PubSubClient.h>
#endif
#include <WebServer.h>
#ifdef NEOPIXEL_ENABLE
    #include <FastLED.h>
#endif

#if (LANGUAGE == 1)
    #include "logmessages.h"
    #include "websiteMgmt.h"
    #include "websiteBasic.h"
#endif
#if (LANGUAGE == 2)
    #include "logmessages_EN.h"
    #include "websiteMgmt_EN.h"
    #include "websiteBasic_EN.h"
#endif

#include <AsyncTCP.h>
#include <ESPAsyncWebServer.h>
#include <ArduinoJson.h>
#include <nvsDump.h>



// Info-docs:
// https://docs.aws.amazon.com/de_de/freertos-kernel/latest/dg/queue-management.html
// https://arduino-esp8266.readthedocs.io/en/latest/PROGMEM.html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

// Loglevels
#define LOGLEVEL_ERROR                  1           // only errors
#define LOGLEVEL_NOTICE                 2           // errors + important messages
#define LOGLEVEL_INFO                   3           // infos + errors + important messages
#define LOGLEVEL_DEBUG                  4           // almost everything

// Serial-logging-configuration
const uint8_t serialDebug = LOGLEVEL_INFO;          // Current loglevel for serial console

// Serial-logging buffer
char logBuf[160];                                   // Buffer for all log-messages

// GPIOs (uSD card-reader)
#define SD_CS                           13          // internal
#define SPI_MOSI                        15          // JT_MTDO
#define SPI_MISO                         2          // Solder to pin7 of SD
#define SPI_SCK                         14          // JT_MTMS

// GPIOs (RFID-readercurrentRfidTagId)
#define MFRC522_RST_PIN                 35          // 14-pin-header
#define MFRC522_CS_PIN                  12          // JT_MTDI
extern SPIClass SPI_MFRC;
MFRC522 mfrc522(MFRC522_CS_PIN, MFRC522_RST_PIN);

// DAC (internal)
#define I2S_DSIN                        25          // internal
#define I2S_BCLK                        27          // internal
#define I2S_LRC                         26          // internal
#define I2S_MCLK                         0          // internal
#define I2S_DOUT                        35          // internal

// I2C GPIOs
#define IIC_CLK                         32          // internal
#define IIC_DATA                        33          // internal

// GPIO used to trigger transistor-circuit / RFID-reader
#define POWER                           19

// GPIOs (Rotary encoder)
#define DREHENCODER_CLK                 5
#define DREHENCODER_DT                  18
#define DREHENCODER_BUTTON              4           // Solder to pin8 of SD

// GPIOs (Control-buttons)                          // Currently deactivated; please read README.md
/*#define PAUSEPLAY_BUTTON                5
#define NEXT_BUTTON                     4
#define PREVIOUS_BUTTON                 33*/

// Amp enable
#define GPIO_PA_EN                      21          // internal

// Headphone?
#define HEADPHONE_PLUGGED_IN            39          // internal

// GPIOs (LEDs)
#define LED_PIN                         23

// Neopixel-configuration
#ifdef NEOPIXEL_ENABLE
    #define NUM_LEDS                    24          // number of LEDs
    #define CHIPSET                     WS2812B     // type of Neopixel
    #define COLOR_ORDER                 GRB
#endif

// Track-Control
#define STOP                            1           // Stop play
#define PLAY                            2           // Start play (currently not used)
#define PAUSEPLAY                       3           // Pause/play
#define NEXTTRACK                       4           // Next track of playlist
#define PREVIOUSTRACK                   5           // Previous track of playlist
#define FIRSTTRACK                      6           // First track of playlist
#define LASTTRACK                       7           // Last track of playlist

// Playmodes
#define NO_PLAYLIST                     0           // If no playlist is active
#define SINGLE_TRACK                    1           // Play a single track
#define SINGLE_TRACK_LOOP               2           // Play a single track in infinite-loop
#define AUDIOBOOK                       3           // Single track, can save last play-position
#define AUDIOBOOK_LOOP                  4           // Single track as infinite-loop, can save last play-position
#define ALL_TRACKS_OF_DIR_SORTED        5           // Play all files of a directory (alph. sorted)
#define ALL_TRACKS_OF_DIR_RANDOM        6           // Play all files of a directory (randomized)
#define ALL_TRACKS_OF_DIR_SORTED_LOOP   7           // Play all files of a directory (alph. sorted) in infinite-loop
#define ALL_TRACKS_OF_DIR_RANDOM_LOOP   9           // Play all files of a directory (randomized) in infinite-loop
#define WEBSTREAM                       8           // Play webradio-stream
#define BUSY                            10          // Used if playlist is created

// RFID-modifcation-types
#define LOCK_BUTTONS_MOD                100         // Locks all buttons and rotary encoder
#define SLEEP_TIMER_MOD_15              101         // Puts uC into deepsleep after 15 minutes + LED-DIMM
#define SLEEP_TIMER_MOD_30              102         // Puts uC into deepsleep after 30 minutes + LED-DIMM
#define SLEEP_TIMER_MOD_60              103         // Puts uC into deepsleep after 60 minutes + LED-DIMM
#define SLEEP_TIMER_MOD_120             104         // Puts uC into deepsleep after 120 minutes + LED-DIMM
#define SLEEP_AFTER_END_OF_TRACK        105         // Puts uC into deepsleep after track is finished + LED-DIMM
#define SLEEP_AFTER_END_OF_PLAYLIST     106         // Puts uC into deepsleep after playlist is finished + LED-DIMM
#define SLEEP_AFTER_5_TRACKS            107         // Puts uC into deepsleep after five tracks
#define REPEAT_PLAYLIST                 110         // Changes active playmode to endless-loop (for a playlist)
#define REPEAT_TRACK                    111         // Changes active playmode to endless-loop (for a single track)
#define DIMM_LEDS_NIGHTMODE             120         // Changes LED-brightness

// Repeat-Modes
#define NO_REPEAT                       0
#define TRACK                           1
#define PLAYLIST                        2
#define TRACK_N_PLAYLIST                3

typedef struct { // Bit field
    uint8_t playMode:                   4;      // playMode
    char **playlist;                            // playlist
    bool repeatCurrentTrack:            1;      // If current track should be looped
    bool repeatPlaylist:                1;      // If whole playlist should be looped
    uint16_t currentTrackNumber:        9;      // Current tracknumber
    uint16_t numberOfTracks:            9;      // Number of tracks in playlist
    unsigned long startAtFilePos;               // Offset to start play (in bytes)
    uint8_t currentRelPos:              7;      // Current relative playPosition (in %)
    bool sleepAfterCurrentTrack:        1;      // If uC should go to sleep after current track
    bool sleepAfterPlaylist:            1;      // If uC should go to sleep after whole playlist
    bool saveLastPlayPosition:          1;      // If playposition/current track should be saved (for AUDIOBOOK)
    char playRfidTag[13];                       // ID of RFID-tag that started playlist
    bool pausePlay:                     1;      // If pause is active
    bool trackFinished:                 1;      // If current track is finished
    bool playlistFinished:              1;      // If whole playlist is finished
    uint8_t playUntilTrackNumber:       6;      // Number of tracks to play after which uC goes to sleep
} playProps;
playProps playProperties;

typedef struct {
    char nvsKey[13];
    char nvsEntry[275];
} nvs_t;

// Configuration of initial values (for the first start) goes here....
// There's no need to change them here as they can be configured via webinterface
// Neopixel
uint8_t initialLedBrightness = 16;                      // Initial brightness of Neopixel
uint8_t ledBrightness = initialLedBrightness;
uint8_t nightLedBrightness = 2;                         // Brightness of Neopixel in nightmode

// MQTT
bool enableMqtt = true;
#ifdef MQTT_ENABLE
    uint8_t mqttFailCount = 3;                              // Number of times mqtt-reconnect is allowed to fail. If >= mqttFailCount to further reconnects take place
    uint8_t const stillOnlineInterval = 60;                 // Interval 'I'm still alive' is sent via MQTT (in seconds)
#endif
// RFID
#define RFID_SCAN_INTERVAL 300                         //in ms
uint8_t const cardIdSize = 4;                           // RFID
// Volume
uint8_t maxVolume = 21;                                 // Maximum volume that can be adjusted
uint8_t minVolume = 0;                                  // Lowest volume that can be adjusted
uint8_t initVolume = 3;                                 // 0...21 (If not found in NVS, this one will be taken)
// Sleep
uint8_t maxInactivityTime = 10;                         // Time in minutes, after uC is put to deep sleep because of inactivity
uint8_t sleepTimer = 30;                                // Sleep timer in minutes that can be optionally used (and modified later via MQTT or RFID)
// FTP
char ftpUser[10] = "esp32";                             // FTP-user
char ftpPassword[15] = "esp32";                         // FTP-password


// Button-configuration (change according your needs)
uint8_t buttonDebounceInterval = 50;                    // Interval in ms to software-debounce buttons
uint16_t intervalToLongPress = 700;                     // Interval in ms to distinguish between short and long press of previous/next-button

// Where to store the backup-file
static const char backupFile[] PROGMEM = "/backup.txt"; // File is written every time a (new) RFID-assignment via GUI is done

// Don't change anything here unless you know what you're doing
// HELPER //
// WiFi
unsigned long wifiCheckLastTimestamp = 0;
// Neopixel
#ifdef NEOPIXEL_ENABLE
    bool showLedError = false;
    bool showLedOk = false;
    bool showPlaylistProgress = false;
    bool showRewind = false;
#endif
// MQTT
#ifdef MQTT_ENABLE
    unsigned long lastOnlineTimestamp = 0;
#endif
// RFID
unsigned long lastRfidCheckTimestamp = 0;
char *currentRfidTagId = NULL;
// Sleep
unsigned long lastTimeActiveTimestamp = 0;              // Timestamp of last user-interaction
unsigned long sleepTimerStartTimestamp = 0;             // Flag if sleep-timer is active
bool gotoSleep = false;                                 // Flag for turning uC immediately into deepsleep
bool lockControls = false;                              // Flag if buttons and rotary encoder is locked
bool bootComplete = false;
// Rotary encoder-helper
int32_t lastEncoderValue;
int32_t currentEncoderValue;
int32_t lastVolume = -1;                                // Don't change -1 as initial-value!
uint8_t currentVolume = initVolume;
////////////

// AP-WiFi
static const char accessPointNetworkSSID[] PROGMEM = "ESPuino";     // Access-point's SSID
IPAddress apIP(192, 168, 4, 1);                         // Access-point's static IP
IPAddress apNetmask(255, 255, 255, 0);                  // Access-point's netmask
bool accessPointStarted = false;


// MQTT-configuration
char mqtt_server[16] = "192.168.2.43";                  // IP-address of MQTT-server (if not found in NVS this one will be taken)
char mqttUser[16] = "mqtt-user";                        // MQTT-user
char mqttPassword[16] = "mqtt-password";                // MQTT-password
#ifdef MQTT_ENABLE
    #define DEVICE_HOSTNAME "ESPuino"                 // Name that that is used for MQTT
    static const char topicSleepCmnd[] PROGMEM = "Cmnd/ESPuino/Sleep";
    static const char topicSleepState[] PROGMEM = "State/ESPuino/Sleep";
    static const char topicTrackCmnd[] PROGMEM = "Cmnd/ESPuino/Track";
    static const char topicTrackState[] PROGMEM = "State/ESPuino/Track";
    static const char topicTrackControlCmnd[] PROGMEM = "Cmnd/ESPuino/TrackControl";
    static const char topicLoudnessCmnd[] PROGMEM = "Cmnd/ESPuino/Loudness";
    static const char topicLoudnessState[] PROGMEM = "State/ESPuino/Loudness";
    static const char topicSleepTimerCmnd[] PROGMEM = "Cmnd/ESPuino/SleepTimer";
    static const char topicSleepTimerState[] PROGMEM = "State/ESPuino/SleepTimer";
    static const char topicState[] PROGMEM = "State/ESPuino/State";
    static const char topicCurrentIPv4IP[] PROGMEM = "State/ESPuino/IPv4";
    static const char topicLockControlsCmnd[] PROGMEM ="Cmnd/ESPuino/LockControls";
    static const char topicLockControlsState[] PROGMEM ="State/ESPuino/LockControls";
    static const char topicPlaymodeState[] PROGMEM = "State/ESPuino/Playmode";
    static const char topicRepeatModeCmnd[] PROGMEM = "Cmnd/ESPuino/RepeatMode";
    static const char topicRepeatModeState[] PROGMEM = "State/ESPuino/RepeatMode";
    static const char topicLedBrightnessCmnd[] PROGMEM = "Cmnd/ESPuino/LedBrightness";
    static const char topicLedBrightnessState[] PROGMEM = "State/ESPuino/LedBrightness";
#endif

char stringDelimiter[] = "#";                               // Character used to encapsulate data in linear NVS-strings (don't change)
char stringOuterDelimiter[] = "^";                          // Character used to encapsulate encapsulated data along with RFID-ID in backup-file


void notFound(AsyncWebServerRequest *request) {
    request->send(404, "text/plain", "Not found");
}
AsyncWebServer wServer(80);
AsyncWebSocket ws("/ws");
AsyncEventSource events("/events");

static const char backupRecoveryWebsite[] PROGMEM = "<p>Das Backup-File wird eingespielt...<br />Zur letzten Seite <a href=\"javascript:history.back()\">zur&uuml;ckkehren</a>.</p>";
static const char restartWebsite[] PROGMEM = "<p>Der ESPuino wird neu gestartet...<br />Zur letzten Seite <a href=\"javascript:history.back()\">zur&uuml;ckkehren</a>.</p>";


// Audio/mp3
SPIClass spiSD(HSPI);
TaskHandle_t mp3Play;
TaskHandle_t rfid;
#ifdef NEOPIXEL_ENABLE
    TaskHandle_t LED;
#endif

// FTP
#ifdef FTP_ENABLE
    FtpServer ftpSrv;
#endif

// Info: SSID / password are stored in NVS
WiFiClient wifiClient;
IPAddress myIP;

// MQTT-helper
#ifdef MQTT_ENABLE
    PubSubClient MQTTclient(wifiClient);
#endif

// Rotary encoder-configuration
ESP32Encoder encoder;

// HW-Timer
hw_timer_t *timer = NULL;
volatile SemaphoreHandle_t timerSemaphore;

// Button-helper
typedef struct {
    bool lastState;
    bool currentState;
    bool isPressed;
    bool isReleased;
    unsigned long lastPressedTimestamp;
    unsigned long lastReleasedTimestamp;
} t_button;
t_button buttons[4];

Preferences prefsRfid;
Preferences prefsSettings;
static const char prefsRfidNamespace[] PROGMEM = "rfidTags";        // Namespace used to save IDs of rfid-tags
static const char prefsSettingsNamespace[] PROGMEM = "settings";    // Namespace used for generic settings

QueueHandle_t volumeQueue;
QueueHandle_t trackQueue;
QueueHandle_t trackControlQueue;
QueueHandle_t rfidCardQueue;


// Prototypes
void accessPointStart(const char *SSID, IPAddress ip, IPAddress netmask);
static int arrSortHelper(const void* a, const void* b);
#ifdef MQTT_ENABLE
    void callback(const char *topic, const byte *payload, uint32_t length);
#endif
void buttonHandler();
void deepSleepManager(void);
void doButtonActions(void);
void doRfidCardModifications(const uint32_t mod);
bool dumpNvsToSd(char *_namespace, char *_destFile);
bool endsWith (const char *str, const char *suf);
bool fileValid(const char *_fileItem);
void freeMultiCharArray(char **arr, const uint32_t cnt);
uint8_t getRepeatMode(void);
bool isNumber(const char *str);
void loggerNl(const char *str, const uint8_t logLevel);
void logger(const char *str, const uint8_t logLevel);
#ifdef MQTT_ENABLE
    bool publishMqtt(const char *topic, const char *payload, bool retained);
#endif
size_t nvsRfidWriteWrapper (const char *_rfidCardId, const char *_track, const uint32_t _playPosition, const uint8_t _playMode, const uint16_t _trackLastPlayed, const uint16_t _numberOfTracks);
void onWebsocketEvent(AsyncWebSocket * server, AsyncWebSocketClient * client, AwsEventType type, void * arg, uint8_t *data, size_t len);
#ifdef MQTT_ENABLE
    void postHeartbeatViaMqtt(void);
#endif
bool processJsonRequest(char *_serialJson);
void randomizePlaylist (char *str[], const uint32_t count);
#ifdef MQTT_ENABLE
    bool reconnect();
#endif
char ** returnPlaylistFromWebstream(const char *_webUrl);
char ** returnPlaylistFromSD(File _fileOrDirectory);
void rfidScanner(void *parameter);
void sleepHandler(void) ;
void sortPlaylist(const char** arr, int n);
bool startsWith(const char *str, const char *pre);
String templateProcessor(const String& templ);
void trackControlToQueueSender(const uint8_t trackCommand);
void rfidPreferenceLookupHandler (void);
void sendWebsocketData(uint32_t client, uint8_t code);
void trackQueueDispatcher(const char *_sdFile, const uint32_t _lastPlayPos, const uint32_t _playMode, const uint16_t _trackLastPlayed);
void volumeHandler(const int32_t _minVolume, const int32_t _maxVolume);
void volumeToQueueSender(const int32_t _newVolume);
wl_status_t wifiManager(void);


/* Wrapper-Funktion for Serial-logging (with newline) */
void loggerNl(const char *str, const uint8_t logLevel) {
  if (serialDebug >= logLevel) {
    Serial.println(str);
  }
}

/* Wrapper-Funktion for Serial-Logging (without newline) */
void logger(const char *str, const uint8_t logLevel) {
  if (serialDebug >= logLevel) {
    Serial.print(str);
  }
}


int countChars(const char* string, char ch) {
    int count = 0;
    int length = strlen(string);

    for (uint8_t i = 0; i < length; i++) {
        if (string[i] == ch) {
            count++;
        }
    }

    return count;
}
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
void loop() {
    volumeHandler(minVolume, maxVolume);
    buttonHandler();
    doButtonActions();
    sleepHandler();
    deepSleepManager();
    rfidPreferenceLookupHandler();
    if (wifiManager() == WL_CONNECTED) {
        #ifdef MQTT_ENABLE
            if (enableMqtt) {
                reconnect();
                MQTTclient.loop();
                postHeartbeatViaMqtt();
            }
        #endif
        #ifdef FTP_ENABLE
            ftpSrv.handleFTP();
        #endif
    }
    #ifdef FTP_ENABLE
        if (ftpSrv.isConnected()) {
            lastTimeActiveTimestamp = millis();     // Re-adjust timer while client is connected to avoid ESP falling asleep
        }
    #endif
}


// Some mp3-lib-stuff (slightly changed from default)
void audio_info(const char *info) {
    snprintf(logBuf, sizeof(logBuf) / sizeof(logBuf[0]), "info        : %s", info);
    loggerNl(logBuf, LOGLEVEL_INFO);
}
void audio_id3data(const char *info) {  //id3 metadata
    snprintf(logBuf, sizeof(logBuf) / sizeof(logBuf[0]), "id3data     : %s", info);
    loggerNl(logBuf, LOGLEVEL_INFO);
}
void audio_eof_mp3(const char *info) {  //end of file
    snprintf(logBuf, sizeof(logBuf) / sizeof(logBuf[0]), "eof_mp3     : %s", info);
    loggerNl(logBuf, LOGLEVEL_INFO);
    playProperties.trackFinished = true;
}
void audio_showstation(const char *info) {
    snprintf(logBuf, sizeof(logBuf) / sizeof(logBuf[0]), "station     : %s", info);
    loggerNl(logBuf, LOGLEVEL_NOTICE);
    char buf[255];
    snprintf(buf, sizeof(buf)/sizeof(buf[0]), "Webradio: %s", info);
    #ifdef MQTT_ENABLE
        publishMqtt((char *) FPSTR(topicTrackState), buf, false);
    #endif
}
void audio_showstreaminfo(const char *info) {
    snprintf(logBuf, sizeof(logBuf) / sizeof(logBuf[0]), "streaminfo  : %s", info);
    loggerNl(logBuf, LOGLEVEL_INFO);
}
void audio_showstreamtitle(const char *info) {
    snprintf(logBuf, sizeof(logBuf) / sizeof(logBuf[0]), "streamtitle : %s", info);
    loggerNl(logBuf, LOGLEVEL_INFO);
}
void audio_bitrate(const char *info) {
    snprintf(logBuf, sizeof(logBuf) / sizeof(logBuf[0]), "bitrate     : %s", info);
    loggerNl(logBuf, LOGLEVEL_INFO);
}
void audio_commercial(const char *info) {  //duration in sec
    snprintf(logBuf, sizeof(logBuf) / sizeof(logBuf[0]), "commercial  : %s", info);
    loggerNl(logBuf, LOGLEVEL_INFO);
}
void audio_icyurl(const char *info) {  //homepage
    snprintf(logBuf, sizeof(logBuf) / sizeof(logBuf[0]), "icyurl      : %s", info);
    loggerNl(logBuf, LOGLEVEL_INFO);
}
void audio_lasthost(const char *info) {  //stream URL played
    snprintf(logBuf, sizeof(logBuf) / sizeof(logBuf[0]), "lasthost    : %s", info);
    loggerNl(logBuf, LOGLEVEL_INFO);
}

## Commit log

2021-02-13 add Kicad-Files from before cc6df6d
2021-02-13 add symbol and footprint for Lolin32-lite source: https://gitlab.com/kicad/libraries/kicad-footprints/-/merge_requests/2554 https://gitlab.com/kicad/libraries/kicad-symbols/-/merge_requests/3148
2021-02-13 Kicad-Files entpacken
    [KopfhoAÌaÌrerbuchse mit PCM5102A.csv, KopfhoAÌaÌrerbuchse mit PCM5102A.kicad_pcb, KopfhoAÌaÌrerbuchse mit PCM5102A.sch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]
2021-02-13 KiCad-Files umbenennen: ESP32_Breakout_Carrier
    [ESPuino.kicad_pcb, ESPuino.sch]
2021-02-13 KiCad-Files umbenennen: Kopfhoererplatine
    [Kopfhoererbuchse mit PCM510.csv, Kopfhoererbuchse mit PCM5102A.kicad_pcb, Kopfhoererbuchse mit PCM5102A.sch]
2021-02-13 KiCad-Files umbenennen: Lolin32
    [Tonuino V2.dsn, Tonuino V2.sch, Wemos_Lolin32.kicad_pcb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]
2021-02-13 KiCad-Files umbenennen: Lolin D32
    [ESPuino D32.dsn, ESPuino D32.kicad_pcb, ESPuino D32.sch]
2021-02-13 KiCad-Files umbenennen: Lolin32 SD_MMC PN5180
    [ESPuino Lolin32 MMC PN5180.dsn, ESPuino Lolin32 MMC PN5180.kicad_pcb, ESPuino Lolin32 MMC PN5180.sch]
2021-02-13 move KiCad files to old location
    [ESPuino D32.dsn, ESPuino D32.kicad_pcb, ESPuino D32.sch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]
2021-02-13 move Lolin32 Lite KiCad libraries - add license notice
2021-02-13 add KiCad-Files from SnapEDA & add license notice
2021-02-13 re-generate gerber files for ESP32_Breakout_Carrier
    [ESPuino-B_Cu.gbr, ESPuino-B_Mask.gbr, ESPuino-B_Paste.gbr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]
2021-02-13 re-generate gerber files for all PCBs
    [ESPuino-B_Cu.gbr, ESPuino-B_Mask.gbr, ESPuino-B_Paste.gbr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]
2021-02-14 use snapEDA footprint and create 3d-model for ESP32_Breakout_Carrier
    [ESPuino.kicad_pcb, ESPuino.sch]
2021-03-02 copy board json files from ~/.platformio/…
2021-03-02 add USB PIDs/VIDs to board json files

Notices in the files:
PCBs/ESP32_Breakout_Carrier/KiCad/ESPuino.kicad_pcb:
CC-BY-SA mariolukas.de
